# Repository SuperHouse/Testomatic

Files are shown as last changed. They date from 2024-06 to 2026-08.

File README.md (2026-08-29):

Testomatic PCB Test Jig System
==============================

Copyright 2024-2026 SuperHouse Automation Pty Ltd  [www.superhouse.tv]()

Testomatic is an open-source PCB test jig system with several goals:

1. Minimise reinvention when creating a test jig for a new **Device
Under Test (DUT)**.
2. Provide enough built-in I/O to **make the majority of tests easy**, with
expandability to **make harder tests possible**.
3. Allow the chassis to be quickly reused for multiple DUTs, with
each DUT having its own **Test Module**.
4. Integration with an **external test management / logging platform** for centralised storage of test results from one or more testers.

Testomatic is based around a Raspberry Pi, with a special PCB to provide additional I/O and protect the Pi from faults that may occur on the DUT. It uses removable Test Modules that provide the mechanical and electrical connection to each specific DUT. Currently we're using a simple Python testrunner script which has support for definition of multiple target boards, and can be controlled via the touchscreen using a control panel created using Node-RED Dashboard v2.

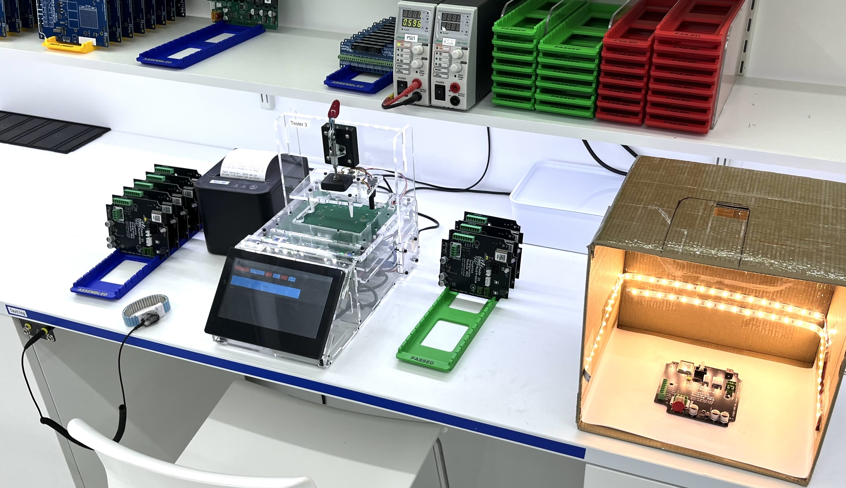
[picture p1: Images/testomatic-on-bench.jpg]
Prototype test jig


This is definitely a work in progress and the design is rapidly
developing. Most development and discussion of this project has taken
place on [SuperHouseTV livestreams](https://www.youtube.com/superhousetv) on YouTube, and on the [SuperHouse
Discord](https://www.superhouse.tv/discord/).

For an overview of how the project came to be and the design goals, see this 
presentation from Everything Open 2026:

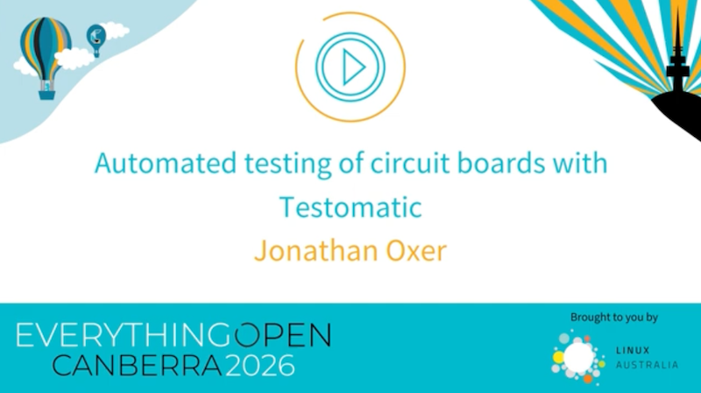
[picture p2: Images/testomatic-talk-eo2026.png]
YouTube (https://www.youtube.com/watch?v=EJt35TPn2Sw)


The new v2 system is still in development and uses a vertically-mounted PCB with a card edge connector for bridging between the Raspberry Pi and the Test Module:

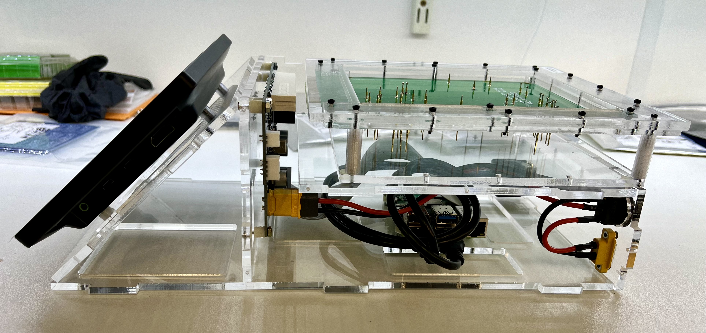
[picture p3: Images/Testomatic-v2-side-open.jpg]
Testomatic v2.0


The v2.3 **Testomatic PCB**:

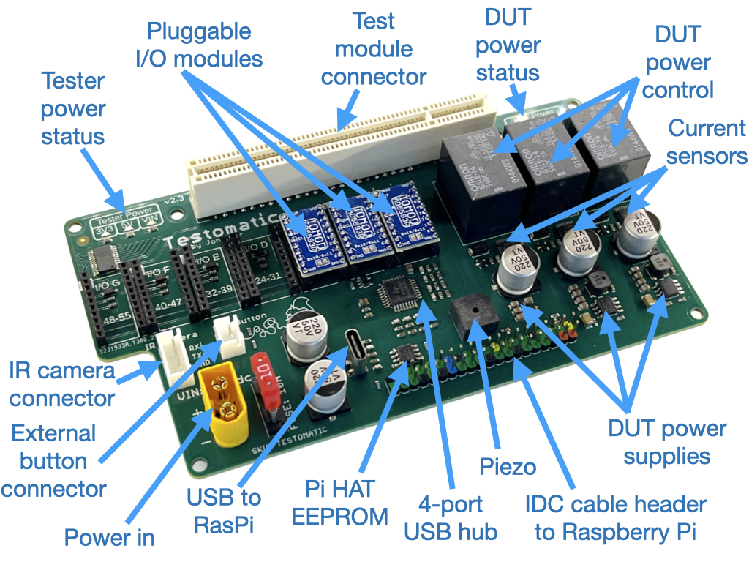
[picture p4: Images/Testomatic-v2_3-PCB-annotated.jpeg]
Testomatic PCB annotated


The **Testomatic PCB** fits into a laser-cut chassis with various other
parts:

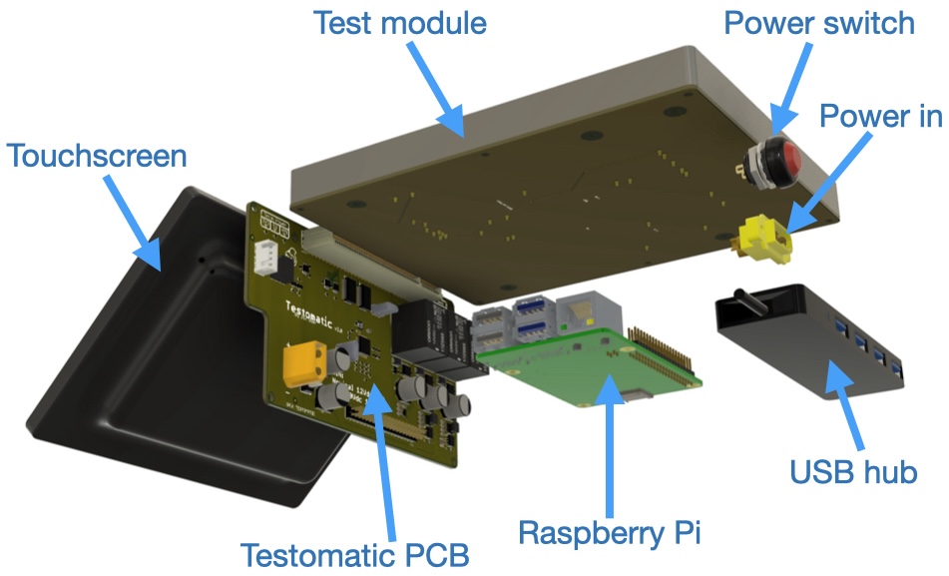
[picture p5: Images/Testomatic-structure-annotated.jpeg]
Testomatic structure


**Test Modules** are built around a **Test Pin Carrier Board (TPCB)** which
uses a card edge connector commonly used for PCI to pass signals
between the Testomatic system and the test pins:

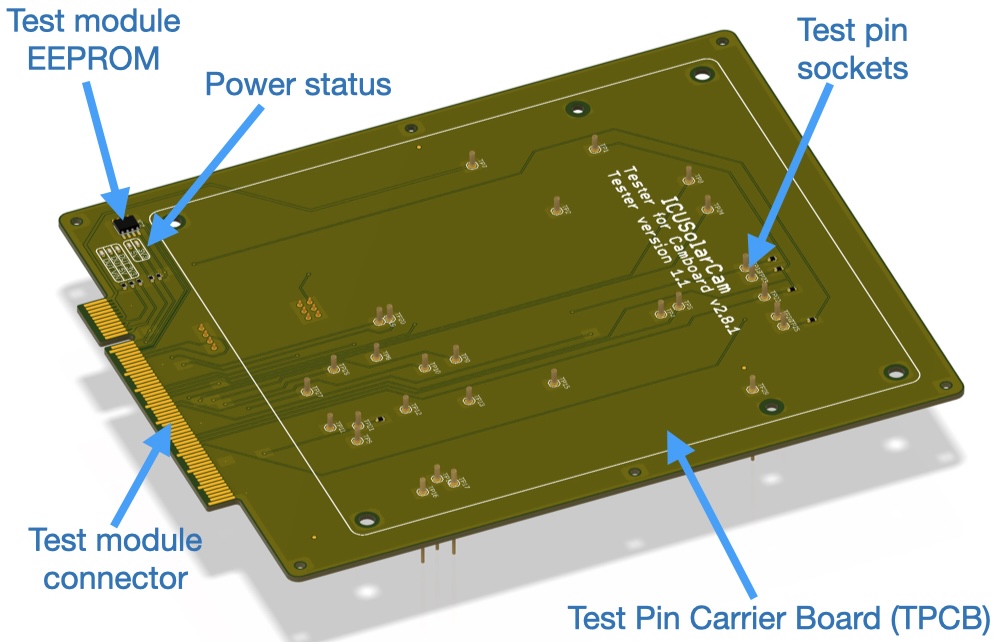
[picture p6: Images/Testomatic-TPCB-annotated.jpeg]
Test Pin Carrier Board


A reference design for the TPCB has been created as a starting point for making DUT-specific versions.

## Features
* 56 GPIOs grouped as 7 blocks, each with 8 pins.
* Each GPIO block can be configured for 3.3V or 5V I/O.
* Each GPIO pin can be digital input, digital output, 12-bit ADC, or 12-bit DAC.
* 4-port USB hub with all 4 ports passed up to the test module.
* SPI and I2C passed up to test module.
* Pi HAT EEPROM on Testomatic PCB for compliance with HAT automatic configuration.
* I2C EEPROM can be placed on Test Module to allow Testomatic to automatically identify which module is loaded.
* 5V power supply dedicated to Raspberry Pi independently of the DUT.
* 5V power supply with current sensing dedicated to DUT.
* 3V3 power supply with current sensing dedicated to DUT.
* VIN is passed to DUT with current sensing.
* Independent relay control of all 3 power rails to DUT.
* 1024 x 600 capacitive touchscreen.
* USB hub mounted in chassis for external connection of receipt printer, barcode scanner, keyboard, etc.
* Support for a 32-24 pixel thermal camera that can be mounted externally for capturing thermal images of the DUT.
* Support for an external button, such as a foot switch for control of test start.

## I/O Modules

Each block of 8 I/O pins is exposed on an I/O Module header, in 2mm pitch DIP format. This allows the use of different I/O modules to suit your needs. A generic I/O Module has been designed based on the AD5593R I2C I/O expander chip. Any pin on this module can be configured to be a digital input or output, analog input, or analog output.

Details of the module are available at [github.com/SuperHouse/IOMOD](https://github.com/SuperHouse/IOMOD)

The plan is to create other modules with different capabilities if required.

## Expansion
Simple tests can be done with the included I/O pins, but many DUTs will require more specific connections. Because the Test Module has SPI, I2C, and USB available, you can build your own custom circuitry directly into the Test Pin Carrier Board. This could include:

* USB-to-Serial converters
* CAN bus interfaces
* RS485 interfaces
* Dummy loads (either onboard or external)
* Light sensors
* Signal generators
* Programmable power supplies

To simplify this process for common tests, we have begun creating small modules that can be added quickly to the design of your Test Pin Carrier Board to save you doing this yourself. These modules include:

 * [USB-to-Serial / ESPFlasher](https://github.com/SuperHouse/ESPFMOD) (complete)
 * [CAN bus](https://github.com/SuperHouse/CANMOD) (complete)
 * [UPDI Programmer / Serial Module](https://github.com/SuperHouse/UPDIMOD)] (complete)

## LED Testing

Instead of relying on visual confirmation by an operator, Testomatic can use light sensors to 
validate correct operation of LEDs. These sensors can detect not only the level of illumination, 
but also the intensity at different wavelengths to verify that the correct colour of LED has 
been placed.

The "ColourSensor" directory contains Fusion design files and STLs for 30mm-long shrouds for 
mounting a VEML3328SL colour sensor, which in turn can be connected via I2C to the Testomatic. 

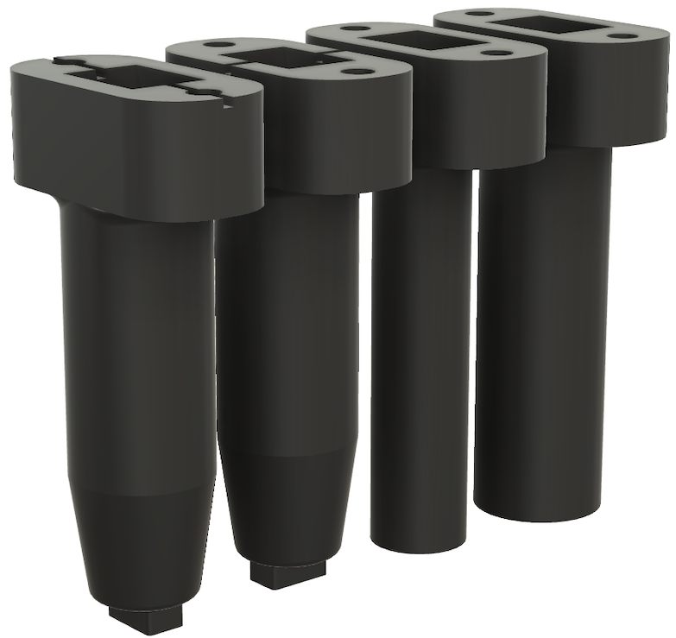
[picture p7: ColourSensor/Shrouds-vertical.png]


Designs are provided to suit 0603 LEDs in both straight and lateral orientations, and 3mm and 
5mm PTH LEDs.

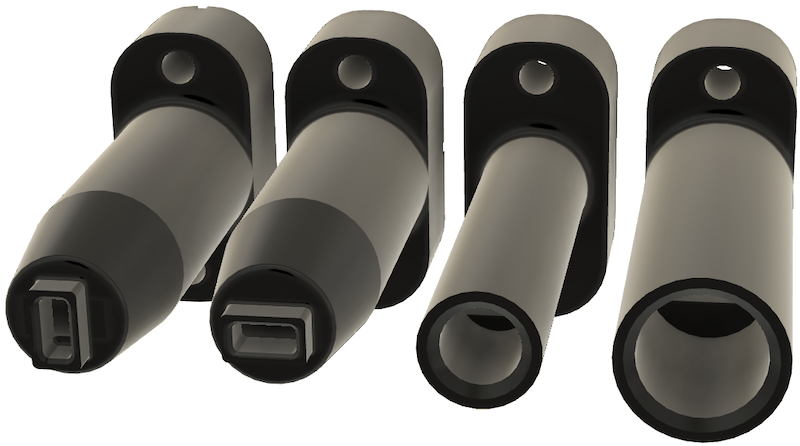
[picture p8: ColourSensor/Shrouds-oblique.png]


The VEML3328SL can be carefully hand-soldered to the ends of thin wires connected to a JST-SH 
1mm connector for compatibility with Qwiic and Stemma, including breakout boards and multiplexers.

The VEML3328SL has a fixed I2C address of 0x10 so a common approach is to use a TCA9548A or 
PCA9546A I2C multiplexer to allow multiple colour sensors to be used.

## Testomatic Circuit Board Register

A closely related project is the Testomatic Circuit Board Register, which is software that 
provides a central location for storing production and testing data related to printed 
circuit board assembly (PCBA) services.

You can use Testomatic without the Register, and you can use the Register without Testomatic, 
but they are being developed in parallel with the intention that they complement each other 
and integrate smoothly.

Lean more about the Register at [github.com/SuperHouse/register](https://github.com/SuperHouse/register).

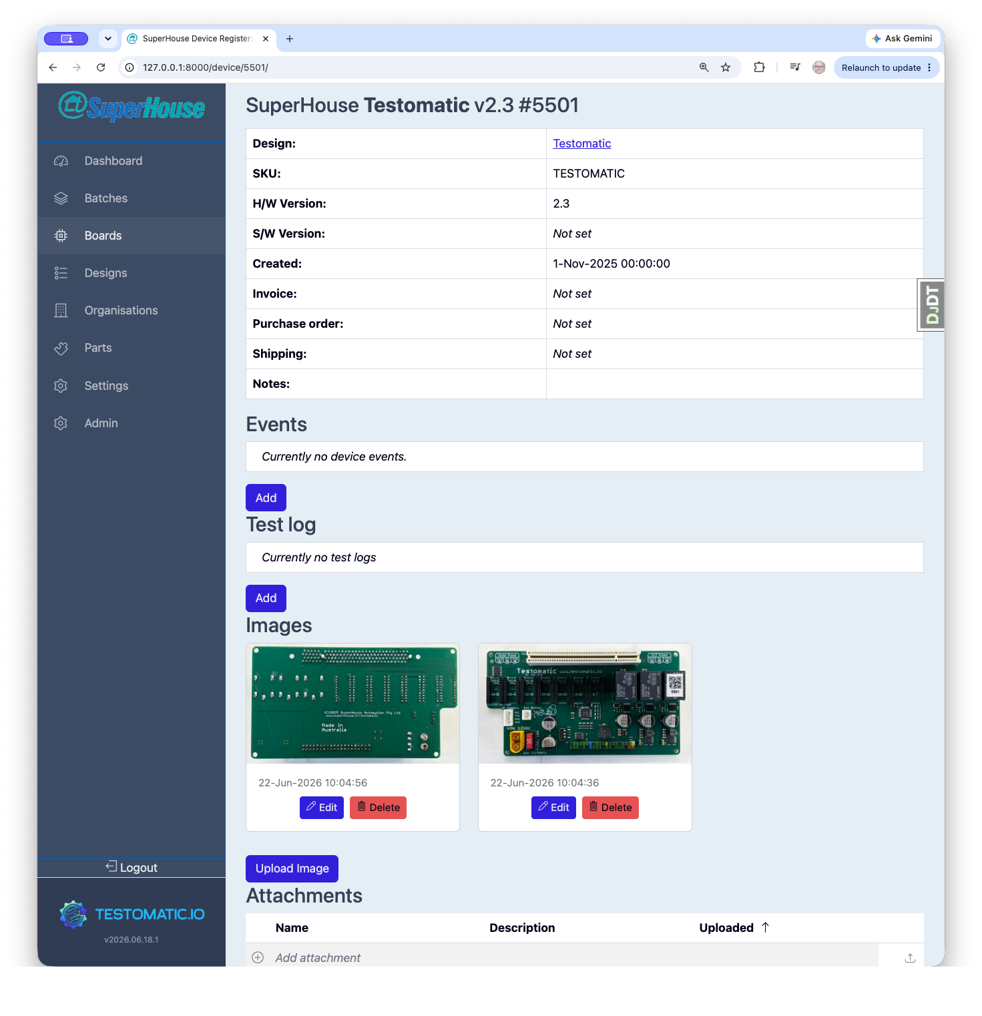
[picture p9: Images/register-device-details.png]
Testomatic v2.0 (https://github.com/SuperHouse/register)


## Installation
Schematic and PCB were created in Fusion360 and exported as EAGLE format,
which can be imported back into Fusion360 or various other packages including KiCAD.

## Terminology
Chassis: A general purpose test jig that can execute tests.

Design: The abstract design of a type of printed circuit board, including the product name, SKU, schematic, PCB layout, bill of materials, and other production data.

Device: An assembled circuit board that is a concrete instantiation of a Design with an identifier such as a serial number that allows it to be unambiguously differentiated from other Devices of the same Design.

Device Under Test / DUT: When a Device is fitted into a Test Module in a Chassis so that it can be tested, it can be referred to as the Device Under Test.

Test Module: Hardware shim that fits into a Chassis and provides connections to a specific DUT.

Test Item: An abstract definition of an action that can be performed while testing a DUT, such as measurign a power rail, or sending a signal to it.

Test Step: An instantiation of a Test Item with specific configuration details such as which power rail to measure, or which I/O pin to use for sending a signal. Test Steps are executed automatically during the process of testing a DUT.

Manual Check: One step that is executed manually during the process of testing a DUT.

Test Suite: A collection of Test Items and Manual Checks that constitutes the steps required to test a DUT.

Test Run: One execution of a Test Suite against a Device Under Test.

Test Output: The data collected during a Test Run, with values and outcomes that are specific to that Device.

Test Result: Pass/Fail/Abort/Error. Pass: all Test Steps executed within required parameters. Fail: Test Suite was completed, but one or more Test Steps were outside required parameters. Abort: Test Suite was not completed because a Test Step caused the process to abort. Error: Test Suite was not completed because an environmental problem prevented execution.

Register: Software system that stores definitions of Designs, Test Items, and Test Suites, along with production data and Test Results related to Devices.

Test Suite Definition: A JSON file that contains the Test Steps and Manual Checks of a Test Suite.

Test Suite Package: A Test Suite Definition together with the additional artifacts it references and requires for execution, such as firmware binaries, whether delivered as a single archive or assembled from multiple sources such as separate API fetches.

Test Runner: Software that runs on the Chassis to load a Test Suite, execute its Test Steps against a Device, and report the resulting Test Results.

## Credits
Designed by Jonathan Oxer <jon@oxer.com.au> with the assistance of many members of the SuperHouse Discord.

## Distribution
The specific terms of distribution of this project are governed by the
license referenced below.

## License
Licensed under the TAPR Open Hardware License (www.tapr.org/OHL).
The "license" folder within this repository also contains a copy of
this license in plain text format.

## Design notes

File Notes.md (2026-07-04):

# Notes

## Sources Of Inspiration

### Thea's tester

 * [https://twitter.com/theavalkyrie/status/1552714810038657025]()
 * [https://github.com/wntrblm/Hubble]()

### OpenHTF

 * [https://www.openhtf.com/]()

### Gundam

Steven's tester for Opulo. This has been mentioned on various livestreams 
etc and the intention seems to be for it to be released as open source, but 
so far I can't find it anywhere. It's referenced in Opulo docs such as here: 

 * [https://ohai.opulo.io/feeder8/oqc/]()

### qabench htf

Looks like a purely commercial offering and I can't find source anywhere. 
Seems to support a large collection of hardware devices.

 * [https://docs.hilster.io/htf/latest/#]()

### Awesome Hardware Test

A massive list of projects. No point reproducing it here!

 * [https://github.com/sschaetz/awesome-hardware-test]()

## To Validate

 * [OK] TUSB2046 USB hub
 * [OK] DUT power control: VIN, 5V, 3V3
 * [OK] INA260 current sensors (Using library)
 * [OK] Piezo beeper
 * [OK] TCA9548 I2C multiplexer
 * [OK] AD5593R I/O expander
 * CAT24C32 EEPROM (Test Module, on I2C bus 1)
 * CAT24C32 EEPROM (HAT, on I2C bus 0)

## Light Box

Logitech Brio MX 4K webcam

sudo apt install fswebcam

To check available resolutions:

v4l2-ctl --list-formats-ext

Must be plugged into USB3 port and detected as a USB3 device to provide 4K res.

fswebcam -r 3840x2160 -p MJPEG --skip 10 test9.jpg

It's only being detected as USB2.0:

lsusb -t

shows 480M (USB2.0) instead of 5000M (USB3.0) even plugged in directly.

According to Gemini, Pi 3B+ only has a shared internal USB2.0 bus, even 
though it exposes USB3 ports externally! This sucks

Got it working an a Pi 5B with a Comsol USB-A to C cable CMAM12BK

Options like this work, although gain doesn't seem to do anything:

fswebcam -r 3840x2160 -p MJPEG --set brightness=100% --set contrast=60% --set sharpness=80% --set gain=255 --skip 20 test17.jpg

### Stacking images

Script to take a series of pics:

#!/bin/bash

### Create a directory for the images if it doesn't exist
mkdir -p webcam_images
cd webcam_images

### Capture 10 images with a 1-second delay between captures
for i in {1..5}; do
    echo "Capturing image $i..."
    # -r specifies resolution, --no-banner removes the timestamp
    # -S 10 skips the first 10 frames to allow calibration
    fswebcam -r 3840x2160 -p MJPEG --no-banner --set brightness=80% --set contrast=60% --set sharpness=60% --skip 20 image_$i.jpeg
    sleep 1
done

echo "Capture complete."

Install ImageMagick:

sudo apt install imagemagick

Process pics:

magick convert *.jpeg -evaluate-sequence median stacked_image.jpeg

## Printer control

Alternative to using external process and passing it a text file:

https://github.com/python-escpos/python-escpos

## Colour sensing

https://github.com/DevelopiumTech/VEML3328

https://www.digikey.com.au/en/products/detail/vishay-semiconductor-opto-division/VEML3328SL/10673128

https://www.finntestelectronics.com/product/mega-module/

## Writing tests

Use Given - When - Then format? Or AAA?

Use raw Python, or some kind of config? Config is hard! For eg:

## How to format error message with results?

Simple string, then output of all "then" lines?

object:
  title: 5V power rail
  abort_on_fail: true
  fail_message: 5V power rail out of spec
  given:
    - 5v: true
    - boolean: true
  when:
    - 5v: true
    - delay: 100ms
  then:
    - analogread a5: 4.7 - 5.1
    
object:
  title: 3V3 power rail
  abort_on_fail: true
  fail_message: 3V3 power rail out of spec
  given:
    - 5v: true
    - boolean: true
  when:
    - 5v: true
    - delay: 100ms
  then:
    - analogread a6: 2.9 - 3.4

## TCA9548 I2C multiplexer

Needs Blinka installed:

https://learn.adafruit.com/circuitpython-on-raspberrypi-linux/installing-circuitpython-on-raspberry-pi

    sudo apt-get update
    sudo apt-get -y upgrade
    sudo apt-get install -y python3-pip

    pip install rpi-lgpio

https://learn.adafruit.com/adafruit-tca9548a-1-to-8-i2c-multiplexer-breakout/circuitpython-python

    sudo pip3 install adafruit-circuitpython-tca9548a

## AD5593R I/O expander

https://github.com/101Robotics/AD5593-MicroPython

https://learn.adafruit.com/adafruit-ad5693r-16-bit-dac-breakout-board/circuitpython-and-python

    python -m venv venv
    source venv/bin/activate
    pip install adafruit-circuitpython-ad569x
    pip install lgpio

## Pi power control

To allow Node-RED to shut down the Pi:

https://flows.nodered.org/node/node-red-contrib-rpi-shutdown

## INA260 current sensors

https://pypi.org/project/ina260/

    pip install ina260
    
    from ina260.controller import Controller
    c = Controller(address=0x40)
    print(c.voltage())
    print(c.current())
    print(c.power()))

## MCP23017 I/O expanders

Use Adafruit Blinka for CP style access to MCP23017 from within Python:

https://learn.adafruit.com/using-mcp23008-mcp23017-with-circuitpython/python-circuitpython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

Created a test script called mcp-test.py

Pullup example:

    pin1.direction = digitalio.Direction.INPUT
    pin1.pull = digitalio.Pull.UP

## DUT Power Control
    pinctrl 17 op dh   // Turn on VIN
    pinctrl 27 op dh   // Turn on 5V
    pinctrl 22 op dh   // Turn on 3.3V

## Piezo control
    pinctrl 23 op dh   // Turn on piezo
    pinctrl 23 op dl   // Turn off piezo

## Data import

Export spreadsheet from gdocs as XLSX, and scp it to the portal VM.

    cd /var/www/register-test/pyproj
    . env/bin/activate
    ./manage.py import-xlsx ~/Device-Serial-Numbers-.xlsx

## Label printer

Brother label printer on Linux: [https://github.com/HenrikBengtsson/brother-ptouch-label-printer-on-linux]()

For CAN:
MCP251863 controller/ transceiver
(See CANPico board)

[https://github.com/kentindell/canhack/tree/master/CANPico]()

[https://core-electronics.com.au/adafruit-picowbell-can-bus-for-pico-mcp2515-can-controller.html]()

[https://github.com/LukePrior/Raspberry-Pi-Thermal-Printer]()

Firmata for Raspberry Pi Pico:

 * Use ConfigurableFirmata with zero changes
 * Board profile is "Arduino Mbed OS RP2040 Boards" -> "Raspberry Pi Pico"
 * Upload methd: UF2

Impressive 3D printed test jig run by a Raspberry Pi:

[https://www.youtube.com/watch?v=iTLnJ0uIZIg]()

Firmata equivalent for RPi Pic:

[https://github.com/MrYsLab/telemetrix-rpi-pico]()

Equivalent to Firmata:

[https://abyz.me.uk/picod/py_picod.html]()

Config files using configparser:

[https://stackoverflow.com/questions/19078170/python-how-would-you-save-a-simple-settings-config-file]()

[https://www.geeksforgeeks.org/how-to-create-gui-applications-under-linux-desktop-using-pygobject/]()

Thermal camera for Raspberry Pi:

[https://www.flir.com.au/developer/lepton-integration/lepton-integration-raspberry-pi/]()

Capturing from Raspberry Pi cam:

    raspistill -st -t 200 -o image.jpg

## Process

Install Raspberry Pi OS 64-bit. Edit the settings:

 * Set hostname to tester(x).local
 * Set username to testomatic
 * Set password to something secret
 * Set WiFi credentials
 * Set WiFi country
 * Set locale
 * Enable SSH

Put SD card in Pi and boot it.

SSH to the pi:

    ssh testomatic@tester.local

Update system and install Vim:

    sudo apt update
    sudo apt dist-upgrade
    sudo apt install vim

Install node-red

Go to http://tester3.local:1880/

Install the palette item "node-red-contrib-ip"
Install the palette item "@flowfuse/node-red-dashboard"

    sudo apt install pipx
    pipx install esptool

Kiosk tutorial: https://www.raspberrypi.com/tutorials/how-to-use-a-raspberry-pi-in-kiosk-mode/

    sudo apt install wtype
    sudo apt install chromium-browser

    sudo vim .config/wayfire.ini

Add this new section:

[autostart]
chromium = chromium-browser http://localhost:1880/dashboard/page1 --kiosk --noerrdialogs --disable-infobars --no-first-run --ozone-platform=wayland --enable-features=OverlayScrollbar --start-maximized

    sudo apt install chromium-browser

Add to /etc/xdg/lxsession/LXDE-pi/autostart:

@xset s off
@xset -dpms
@xset s noblank
@chromium-browser --noerrdialogs --disable-infobars --kiosk https://localhost:1880/dashboard/page1

### Enable Screen

edit /boot/firmware/config.txt and find this line:

    dtoverlay = vc4-kms-v3d

Replace it with:

    dtoverlay = vc4-fkms-v3d

    sudo vim /boot/firmware/config.txt
    
Add these lines to the end:

    hdmi_force_hotplug=1
    max_usb_current=1
    hdmi_group=2
    hdmi_mode=1
    hdmi_mode=87
    hdmi_cvt 1024 600 60 6 0 0 0
    hdmi_drive=1

Elecrow 7" touchscreen setup: [https://www.elecrow.com/rc070p-7-inch-1024x600-raspberry-pi-monitor-touchscreen-capacitive-ips-display-with-built-in-speaker-stand.html](https://www.elecrow.com/rc070p-7-inch-1024x600-raspberry-pi-monitor-touchscreen-capacitive-ips-display-with-built-in-speaker-stand.html)

### Receipt Printer Driver

copy printer-driver-pos_3.13.11_all.deb to machine

    sudo dpkg -i printer-driver-pos_3.13.11_all.deb

Open printer preferences and enable network administration.

Use a browser to connect to https://tester.local:631

Add local printer.

Select the POS-80.

On the printer type page, select Make -> POS
Select Model -> POS-80 (en)

### Install Software

Copy over test software directory.

    pip3 install pytz
    pip3 install esptool

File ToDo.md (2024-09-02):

Testomatic To Do
================

 * Silkscreen on XT60 footprint.
 * Reverse protection diode on VIN. Mitchell says full bridge rectifier. Which is ridiculous. But also awesome.
 * Increase thermal relief widths on edge connector GND pins and XT60 connector.
 * Length-match USB traces.
 * Add solder wicking area beside USB mechanical holes
 * Add bolt holes to XT60 footprint for panel mount version of connector (maybe)
 * Connector for RGB LED strip to illuminate enclosure.
 * Blatantly steal Austin's Smart Hub design
 * Solder-nuts on PCB to avoid standoffs. Thanks Austin!

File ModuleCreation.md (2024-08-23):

= Creating a Test Module

The Test Module supports the DUT mechanically, and connects it electrically
to the test system.

== Laser-cut frame

1. Open "Module Plate Template" in Fusion360.
2. Open "Modify" -> "Parameters".
3. Set "DUTWidth" to the horizontal width of your DUT.
4. Set "DUTLength" to the front-back length of your DUT.
5. Set "DUTFrontOffset" to the distance from the front of your Test Pin Carrier Board and the front edge of your DUT when mounted on it.
6. Close parameters dialog.
7. Turn on Bodies -> Top Plate AND Bottom Plate.
8. Create mounting holes to suit the design of your Test Pin Carrier Board.
9. Turn on only Bodies -> Top Plate, select top surface, and save as DXF for lasercutting.
10. Turn on only Bodies -> Bottom Plate, select top surface, and save as DXF for lasercutting.
11. Laser-cut both parts using 4.5mm acrylic. The thickness of the bottom plate is critical to set the vertical alignment of the connector.
12. Bolt the Top Plate and the Bottom Plate together using M2 bolts. You can optionally countersink them for a smooth top surface.
13. Bolt your Test Pin Carrier Board to the bottom of the assembly.

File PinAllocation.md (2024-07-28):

Raspberry Pi Pins
=================

IO0: Raspberry Pi HAT EEPROM I2C SDA. EEPROM is on the Testomatic main board.

IO1: Raspberry Pi HAT EEPROM I2C SCL. EEPROM is on the Testomatic main board.

IO2: General purpose I2C SDA. Can be used for peripherals on the breakout.

IO3: General purpose I2C SCL. Can be used for peripherals on the breakout.

IO4: Spare

IO5: Spare

IO6: Spare

IO7: SPI CE1

IO8: SPI CE0

IO9: SPI MISO

IO10: SPI MOSI

IO11: SPI SCK

IO13: Spare

IO14: Infrared camera TX (to the Rx of the camera)

IO15: Infrared camera RX (to the Tx of the camera)

IO16: Spare

IO17: Spare

IO18: Tester reset. Active low, with 10K pullup. Connected to !RESET pins on devices that are part of the tester.

IO19: Spare

IO20: External button. Active low, with 10K pullup. Short to GND to activate. Can be used by tester to begin test, etc.

IO21: Spare

IO22: Spare

IO23: Piezo buzzer. Active high.

IO24: Available on tester breakout. Can be used as an SPI CE, for example.

IO25: Available on tester breakout. Can be used as an SPI CE, for example.

IO26: Spare

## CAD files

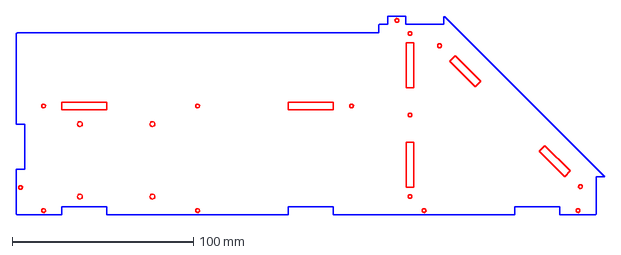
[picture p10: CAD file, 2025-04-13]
Chassis/Side Plate Right.dxf
324.8 x 109.6 mm

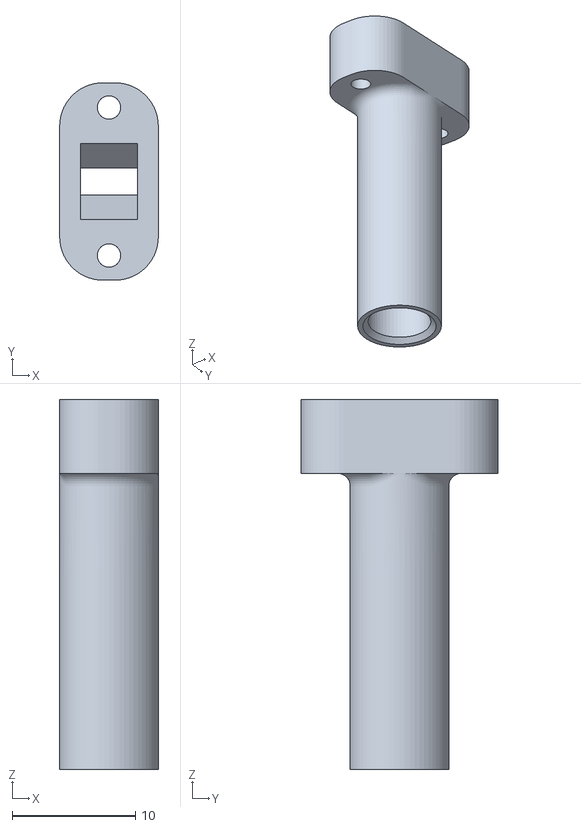
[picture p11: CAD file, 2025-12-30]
ColourSensor/Shroud 5mm.stl
8.00 x 16.0 x 30.0

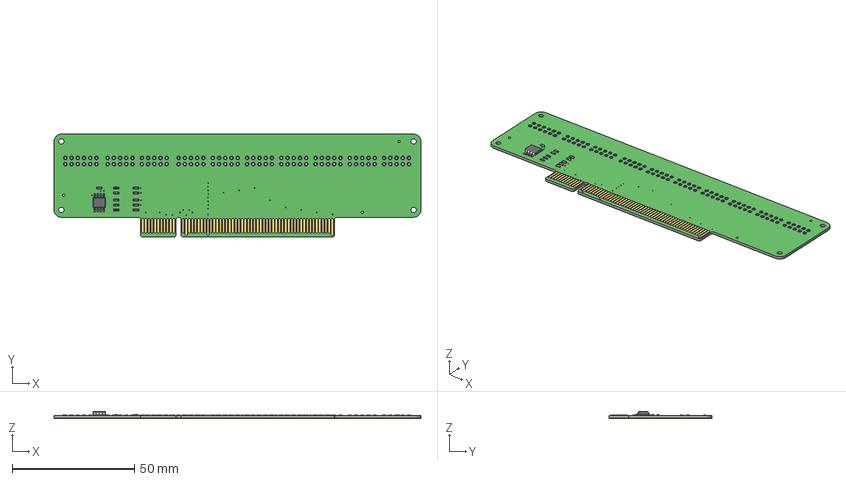
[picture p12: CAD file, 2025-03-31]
TestModules/TMMOD-BREAKOUT-v1_1.3mf
150.0 x 42.0 x 2.80 mm
Board
CopperHoles

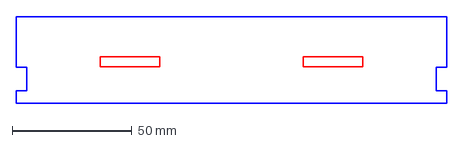
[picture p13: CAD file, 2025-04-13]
Chassis/Cap Plate.dxf
180.2 x 36.2 mm

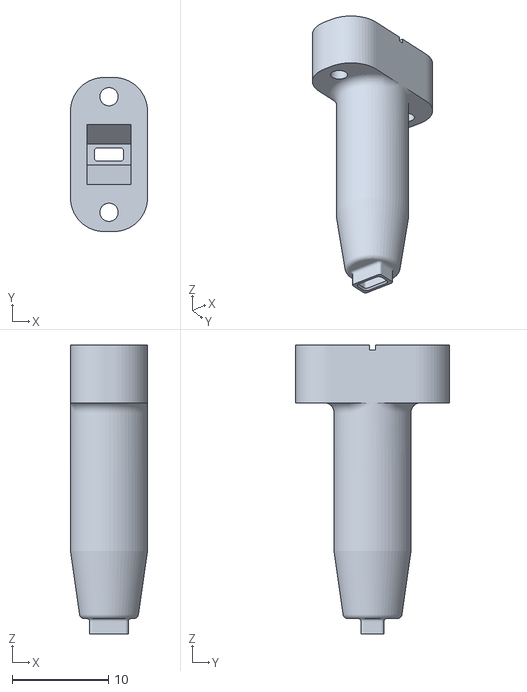
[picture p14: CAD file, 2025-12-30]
ColourSensor/Shroud 0603 lateral.stl
8.00 x 16.0 x 30.0

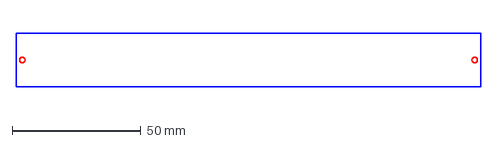
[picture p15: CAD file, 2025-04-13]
Chassis/Chin Plate.dxf
180.2 x 20.7 mm

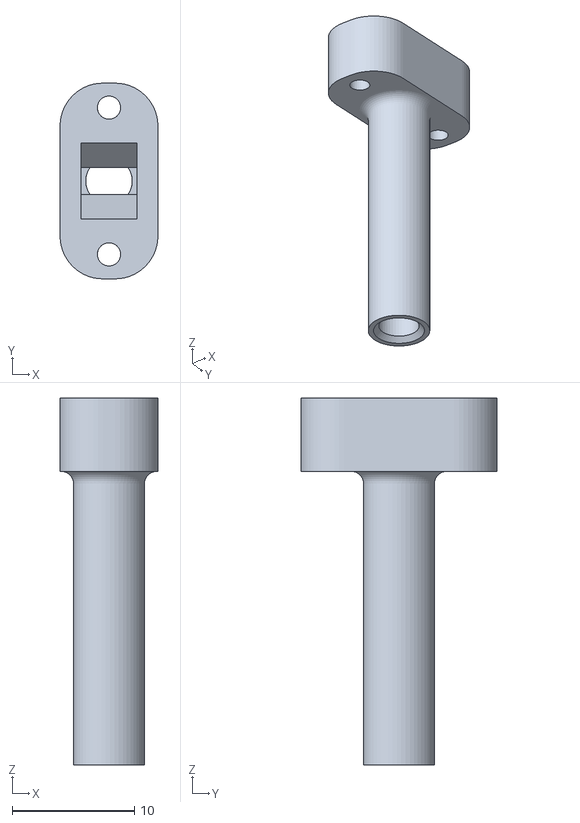
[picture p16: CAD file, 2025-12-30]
ColourSensor/Shroud 3mm.stl
8.00 x 16.0 x 30.0

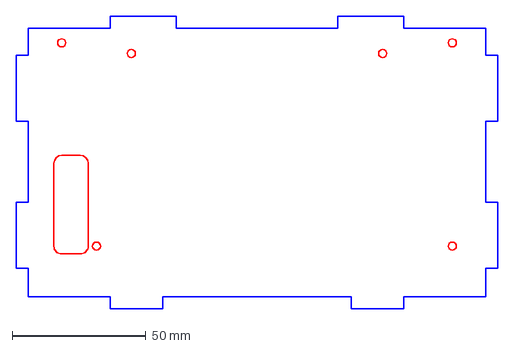
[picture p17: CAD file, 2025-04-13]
Chassis/PCB Plate.dxf
179.8 x 109.3 mm

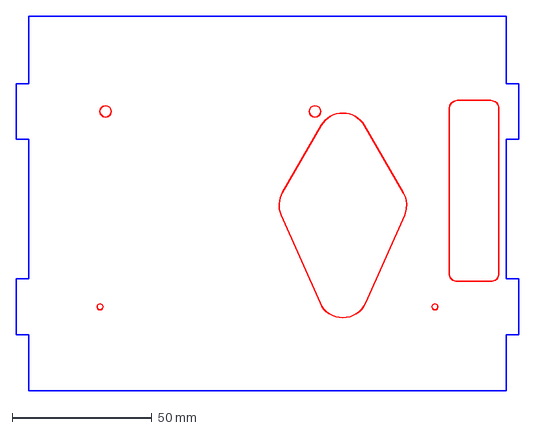
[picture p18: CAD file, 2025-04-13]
Chassis/Display Plate.dxf
180.2 x 134.1 mm

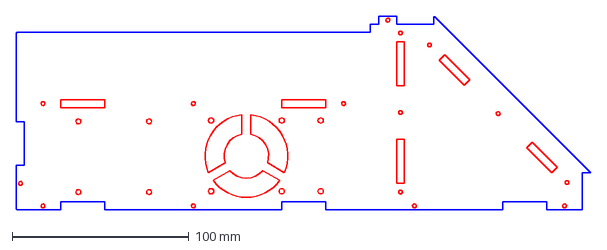
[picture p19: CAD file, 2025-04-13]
Chassis/Side Plate Left.dxf
324.8 x 109.6 mm

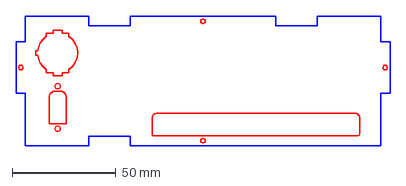
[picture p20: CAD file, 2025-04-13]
Chassis/Back Plate.dxf
180.2 x 62.2 mm

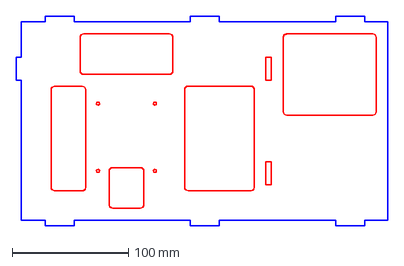
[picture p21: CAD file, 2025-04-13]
Chassis/Base Plate.dxf
320.1 x 180.1 mm

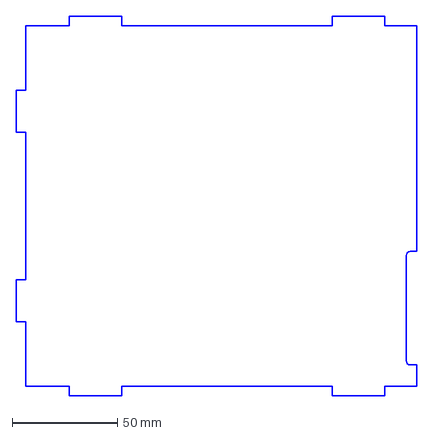
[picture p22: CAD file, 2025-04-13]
Chassis/Deck Plate.dxf
190.1 x 180.1 mm

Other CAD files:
ColourSensor/Shroud 0603 straight.stl
Chassis/Back Plate.f3d
Chassis/Base Plate.f3d
Chassis/Cap Plate.f3d
Chassis/Chin Plate.f3d
Chassis/Deck Plate.f3d
Chassis/Display Plate.f3d
Chassis/PCB Plate.f3d
Chassis/Side Plate Left.f3d
Chassis/Side Plate Right.f3d
ColourSensor/Shroud 0603 lateral.f3d
ColourSensor/Shroud 0603 straight.f3d
ColourSensor/Shroud 3mm.f3d
ColourSensor/Shroud 5mm.f3d
TestModules/Module Plate Template.f3d

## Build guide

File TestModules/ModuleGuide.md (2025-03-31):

Creating a Test Module
======================

The Test Module supports the DUT mechanically, and connects it electrically
to the test system.

You need to create one test module for each type of device that you wish to test. Test modules
can be swapped out as required.

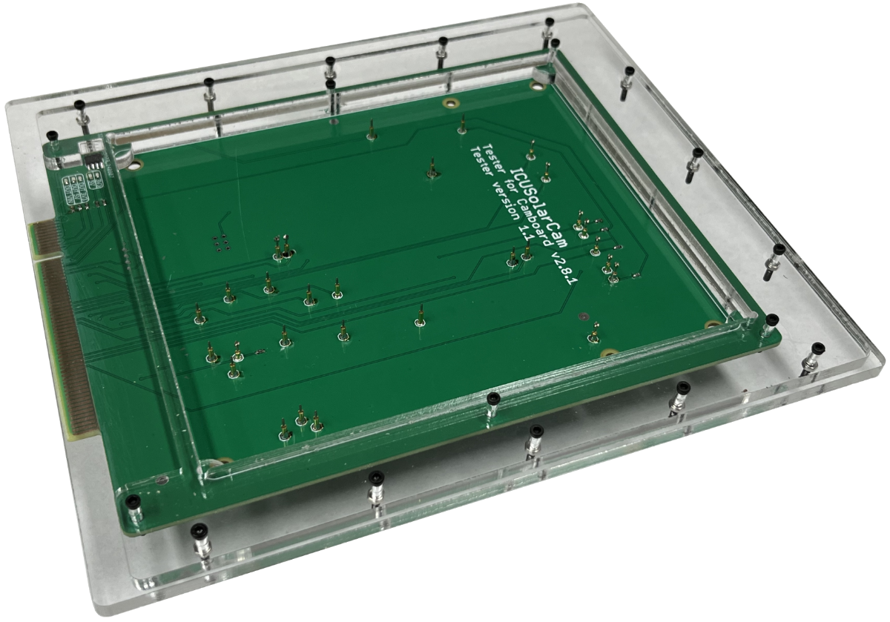
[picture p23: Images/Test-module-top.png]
Test module


## Test Pin Carrier Board (TPCB)

To do: Notes here about designing your TPCB.

## Laser-cut frame

1. Open "Module Plate Template" in Fusion360.
2. Open "Modify" -> "Parameters".

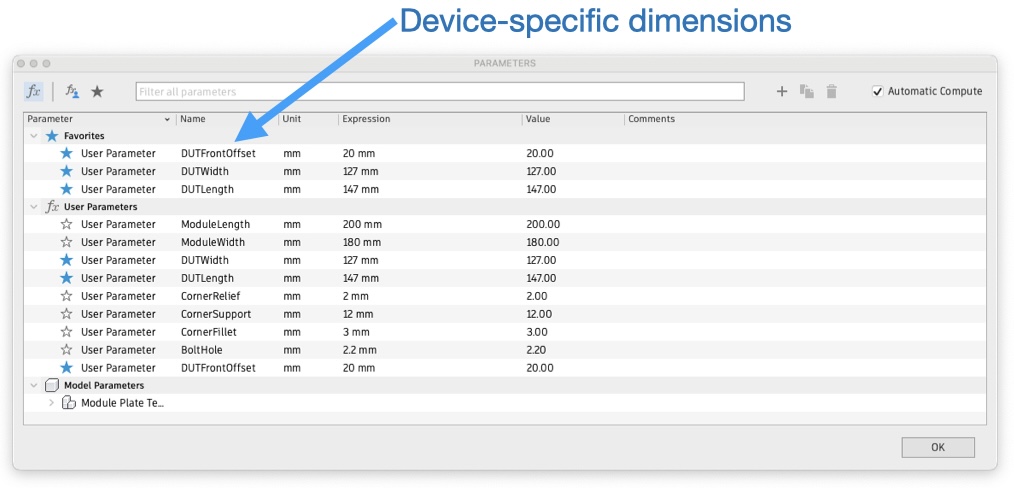
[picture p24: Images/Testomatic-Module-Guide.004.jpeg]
Module parameters


3. Set "DUTWidth" to the horizontal width of your DUT.
4. Set "DUTLength" to the front-back length of your DUT.
5. Set "DUTFrontOffset" to the distance from the front of your Test Pin Carrier Board and the front edge of your DUT when mounted on it.
6. Close parameters dialog.
7. Turn on Bodies -> Top Plate AND Bottom Plate.
8. Create mounting holes to suit the design of your Test Pin Carrier Board.
9. Turn on only Bodies -> Top Plate, select top surface, and save as DXF for lasercutting.
10. Turn on only Bodies -> Bottom Plate, select top surface, and save as DXF for lasercutting.

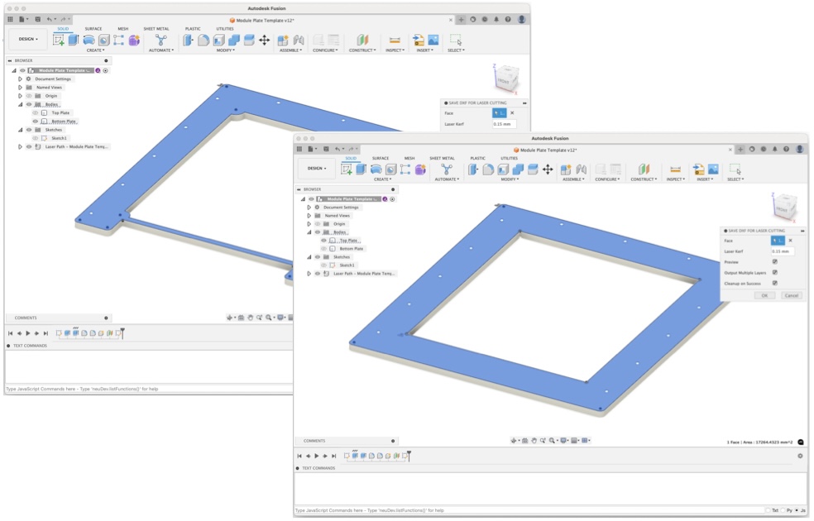
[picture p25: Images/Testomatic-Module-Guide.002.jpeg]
Export for lasercutting


11. Laser-cut both parts using 4.5mm acrylic. The thickness of the bottom plate is critical to set the vertical alignment of the connector.
12. Bolt the Top Plate and the Bottom Plate together using M2 bolts. You can optionally countersink them for a smooth top surface.
13. Bolt your Test Pin Carrier Board to the bottom of the assembly.

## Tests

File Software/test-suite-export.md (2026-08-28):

# Test Suite Export Format

A Test Suite is the ordered list of Test Steps and Manual Checks for a
[Design](../user-guide/designs.md). You can download a Test Suite as a single JSON file. This
page describes that JSON format. Use it to build external tools, such as a Testomatic tester,
that read or write Test Suites.

## Downloading a Test Suite

Only staff users can download a Test Suite. To download one, open the Design detail page and go
to the **Test Suite** tab. Click **Download**.

The download contains the version shown on the tab. This is the draft version if one exists. If
not, it is the current saved version.

The filename follows this pattern:

```
{sku}-hw{hw_version}-test-suite-v{version}.json
```

For example, `abc123-hw1-0-test-suite-v3.json`.

## Envelope structure

The file is a single JSON object with four top-level keys:

```json
{
  "export_schema_version": 1,
  "design": { "...": "..." },
  "test_suite": { "...": "..." },
  "test_steps": [ "..." ],
  "manual_checks": [ "..." ]
}
```

`export_schema_version` identifies the shape of the envelope: its top-level keys and their
nesting. The Register increases this number only when that shape changes, for example when a
top-level key changes name. It differs from `config_schema_version`, described below, which
tracks the shape of one step's own configuration fields.

### `design`

This object identifies the Design that the Test Suite belongs to:

| Field | Type | Description |
|---|---|---|
| `id` | integer | The Design's database ID |
| `sku` | string | The Design's SKU |
| `name` | string | The Design's name |
| `hw_version` | string | The Design's hardware version |

### `test_suite`

This object describes this version of the Test Suite:

| Field | Type | Description |
|---|---|---|
| `version` | integer | Version number, starting at 1 |
| `status` | string | `"DRAFT"` or `"SAVED"` |
| `notes` | string or `null` | Free-text notes the user enters when saving this version |
| `created_dt` | string | ISO 8601 timestamp showing when the Register created this version |

### `test_steps`

This is an array of Test Step objects, listed in execution order. Every step has the same outer
shape, regardless of type:

| Field | Type | Description |
|---|---|---|
| `order` | integer | Position within the suite (ascending) |
| `step_type` | string | One of the step type codes listed below |
| `name` | string | The step's display name |
| `hard_fail` | boolean | If `true`, a failure of this step stops the rest of the suite |
| `config_schema_version` | integer or `null` | The schema version of `config` below (`null` if the step predates schema versioning) |
| `config` | object | Type-specific configuration fields. See [Test Step types](#test-step-types) below |

`config_schema_version` copies the `schema_version` key already inside `config`. The Register
places it at this outer level so a consumer does not need to open the nested object to find it.
This number increases only when a step type's own config fields change shape. It is independent
of `export_schema_version` above.

### `manual_checks`

This is an array of Manual Check objects, listed in order. It is a plain checklist shown
alongside the Test Steps. Each item has no type or config fields of its own:

| Field | Type | Description |
|---|---|---|
| `order` | integer | Position within the list (ascending) |
| `text` | string | The checklist item's text |

## Test Step types

Each step's `config` object holds only the fields for its `step_type`. The Register omits an
**optional** field from `config` when it has no value. A consumer should apply its own default
instead of expecting a null or empty value for that key.

### `DELAY`

Waits a fixed number of milliseconds.

| Field | Type | Required | Description |
|---|---|---|---|
| `delay_ms` | integer | Yes | Delay in milliseconds |

### `UPLOAD_FIRMWARE`

Uploads a firmware image to the device under test.

| Field | Type | Required | Description |
|---|---|---|---|
| `upload_tool` | string | Yes | One of `avrdude`, `esptool.py`, `openocd`, `stm32cubeprogrammer` |
| `port` | string | Yes | Serial port / device identifier |
| `firmware_file` | string | Yes | Firmware binary filename |

### `BEEP`

Sounds a beep, or a sequence of beeps.

| Field | Type | Required | Description |
|---|---|---|---|
| `duration_ms` | integer | Yes | Duration of each beep, in milliseconds |
| `count` | integer | No | Number of beeps. A consumer should use `1` as the default when this field is absent |

### `READ_RAIL_VOLTAGE`

Reads a power rail's voltage. Checks that the reading falls within the given range.

| Field | Type | Required | Description |
|---|---|---|---|
| `rail` | string | Yes | One of `3.3V`, `5V`, `12V` |
| `min_v` | number | Yes | Minimum acceptable voltage |
| `max_v` | number | Yes | Maximum acceptable voltage |

### `READ_RAIL_CURRENT`

Reads a power rail's current draw. Checks that the reading falls within the given range.

| Field | Type | Required | Description |
|---|---|---|---|
| `rail` | string | Yes | One of `3.3V`, `5V`, `12V` |
| `min_ma` | number | Yes | Minimum acceptable current, in mA |
| `max_ma` | number | Yes | Maximum acceptable current, in mA |

### `CONTROL_POWER_RAIL`

Turns a power rail on or off.

| Field | Type | Required | Description |
|---|---|---|---|
| `rail` | string | Yes | One of `3.3V`, `5V`, `12V` |
| `action` | string | Yes | `ON` or `OFF` |

### `PYTHON`

Runs a block of Python code as the test step. The Register does not execute this code. It is
configuration data for a Testomatic tester, or another consumer, to run.

| Field | Type | Required | Description |
|---|---|---|---|
| `python_code` | string | Yes | Python source code |

### `IOMOD_ANALOG_READ`

Reads an analog value from an IOMOD pin. Optionally checks that the value falls within a range.

| Field | Type | Required | Description |
|---|---|---|---|
| `iomod` | string | Yes | IOMOD identifier, `A`–`G` |
| `pin` | string | Yes | Pin number, `0`–`7` |
| `expect_min` | integer | No | Minimum acceptable reading |
| `expect_max` | integer | No | Maximum acceptable reading |

### `IOMOD_DIGITAL_READ`

Reads a digital value from an IOMOD pin. Checks the value against an expected value.

| Field | Type | Required | Description |
|---|---|---|---|
| `iomod` | string | Yes | IOMOD identifier, `A`–`G` |
| `pin` | string | Yes | Pin number, `0`–`7` |
| `expect` | string | Yes | Expected value, `"0"` or `"1"` |

### `IOMOD_DIGITAL_WRITE`

Writes a digital value to an IOMOD pin.

| Field | Type | Required | Description |
|---|---|---|---|
| `iomod` | string | Yes | IOMOD identifier, `A`–`G` |
| `pin` | string | Yes | Pin number, `0`–`7` |
| `digital_write` | string | Yes | Value to write, `"0"` or `"1"` |

### `IOMOD_ANALOG_WRITE`

Writes an analog value to an IOMOD pin.

| Field | Type | Required | Description |
|---|---|---|---|
| `iomod` | string | Yes | IOMOD identifier, `A`–`G` |
| `pin` | string | Yes | Pin number, `0`–`7` |
| `analog_write` | integer | Yes | Value to write |

### `LED_SPECTRAL_READING`

Reads color and light values from an I2C spectral sensor. The sensor may connect through a MUX.
The step can optionally check that each channel falls within a range.

| Field | Type | Required | Description |
|---|---|---|---|
| `i2c_addr` | string | Yes | Sensor's I2C address, as hex text, for example `"0x29"` |
| `mux_chan` | string | Yes | MUX channel, `0`–`7` |
| `mux_addr` | string | No | MUX's I2C address, as hex text, for example `"0x71"`. Omitted if the board has no MUX in the path |
| `r_min` / `r_max` | integer | No | Red channel acceptable range |
| `g_min` / `g_max` | integer | No | Green channel acceptable range |
| `b_min` / `b_max` | integer | No | Blue channel acceptable range |
| `lux_min` / `lux_max` | integer | No | Lux (brightness) acceptable range |
| `ir_min` / `ir_max` | integer | No | Infrared channel acceptable range |

### `OPERATOR_INTERVENTION`

Displays an instruction to a human operator and waits for the operator to act. Unlike other step
types, it does not take an automated reading.

| Field | Type | Required | Description |
|---|---|---|---|
| `message` | string | Yes | Instruction text shown to the operator |

## Example

```json
{
  "export_schema_version": 1,
  "design": {
    "id": 42,
    "sku": "ABC123",
    "name": "Example Board",
    "hw_version": "1.0"
  },
  "test_suite": {
    "version": 3,
    "status": "SAVED",
    "notes": "Added LED spectral check",
    "created_dt": "2026-08-20T09:15:00+10:00"
  },
  "test_steps": [
    {
      "order": 1,
      "step_type": "DELAY",
      "name": "Settle",
      "hard_fail": false,
      "config_schema_version": 1,
      "config": { "schema_version": 1, "delay_ms": 250 }
    },
    {
      "order": 2,
      "step_type": "READ_RAIL_VOLTAGE",
      "name": "Check 5V rail",
      "hard_fail": true,
      "config_schema_version": 1,
      "config": { "schema_version": 1, "rail": "5V", "min_v": 4.8, "max_v": 5.2 }
    },
    {
      "order": 3,
      "step_type": "LED_SPECTRAL_READING",
      "name": "Check status LED",
      "hard_fail": false,
      "config_schema_version": 1,
      "config": {
        "schema_version": 1,
        "i2c_addr": "0x29",
        "mux_addr": "0x71",
        "mux_chan": "2",
        "r_min": 100, "r_max": 255
      }
    }
  ],
  "manual_checks": [
    { "order": 1, "text": "Confirm LED lights up green" }
  ]
}
```

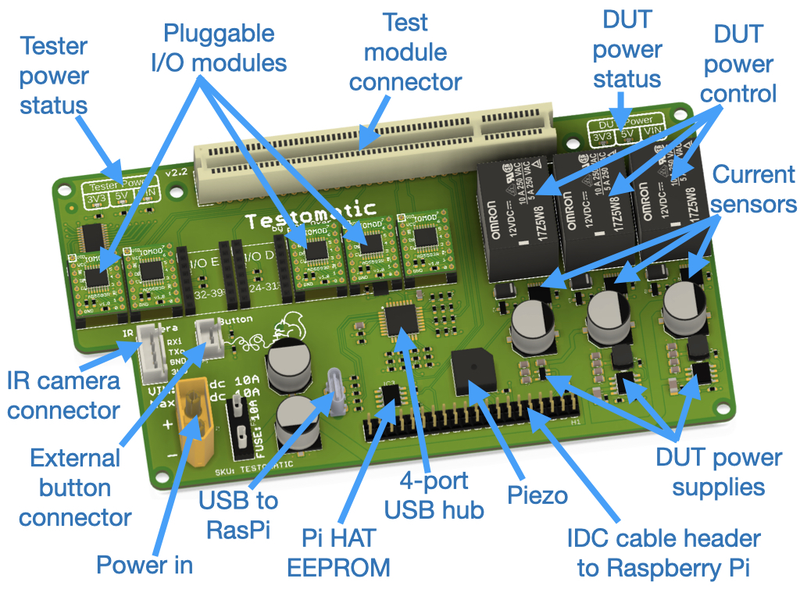
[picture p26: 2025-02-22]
Images/Testomatic-v2_2-PCB-annotated.jpeg

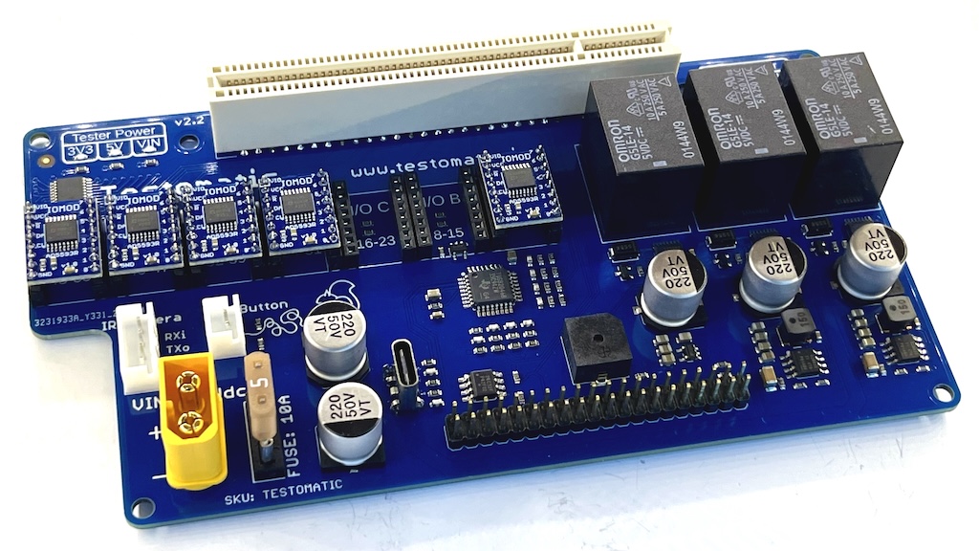
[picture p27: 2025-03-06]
Images/Testomatic-v2_2-pcb-oblique.jpg

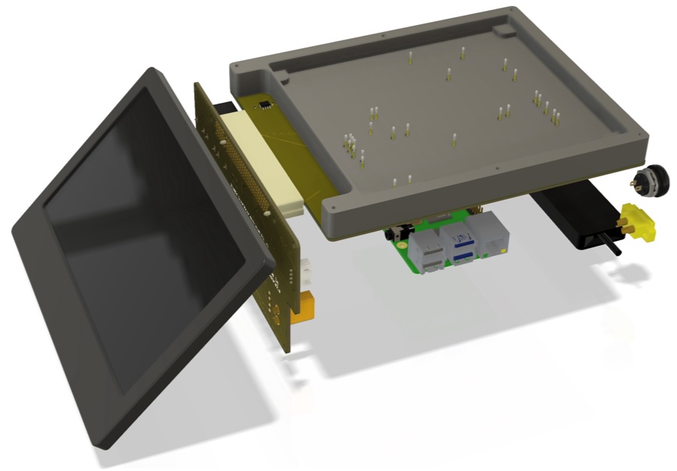
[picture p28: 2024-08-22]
Images/Testomatic-v2.jpeg

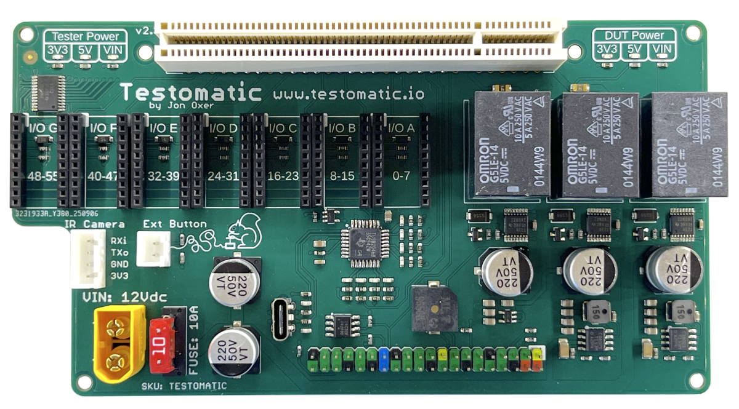
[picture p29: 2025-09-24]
Images/Testomatic-PCB-v2_3-top.png

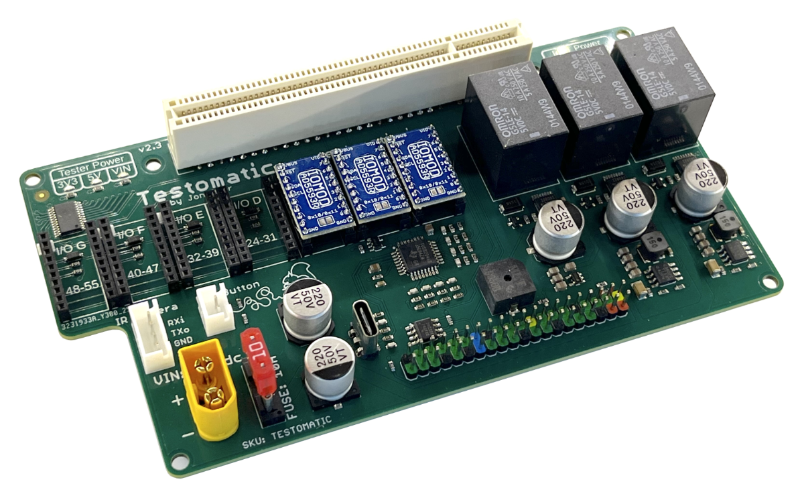
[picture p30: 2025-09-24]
Images/Testomatic-PCB-v2_3-oblique.png

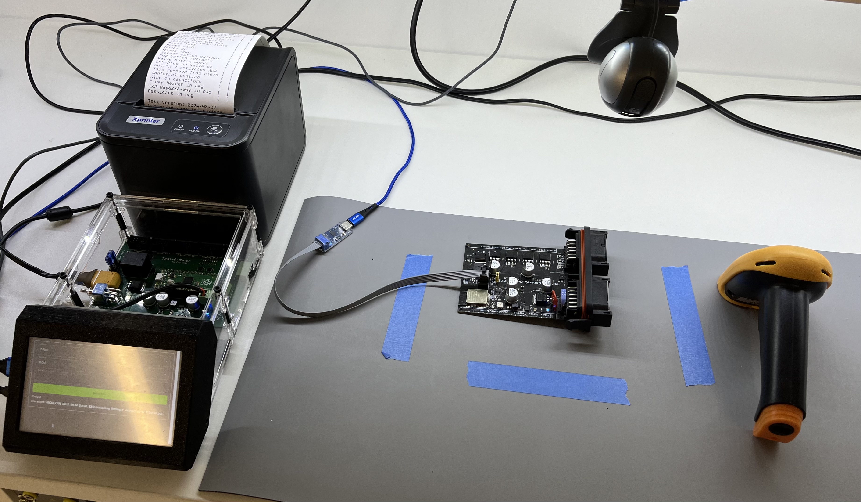
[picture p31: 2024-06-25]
Images/Test-jig.jpg

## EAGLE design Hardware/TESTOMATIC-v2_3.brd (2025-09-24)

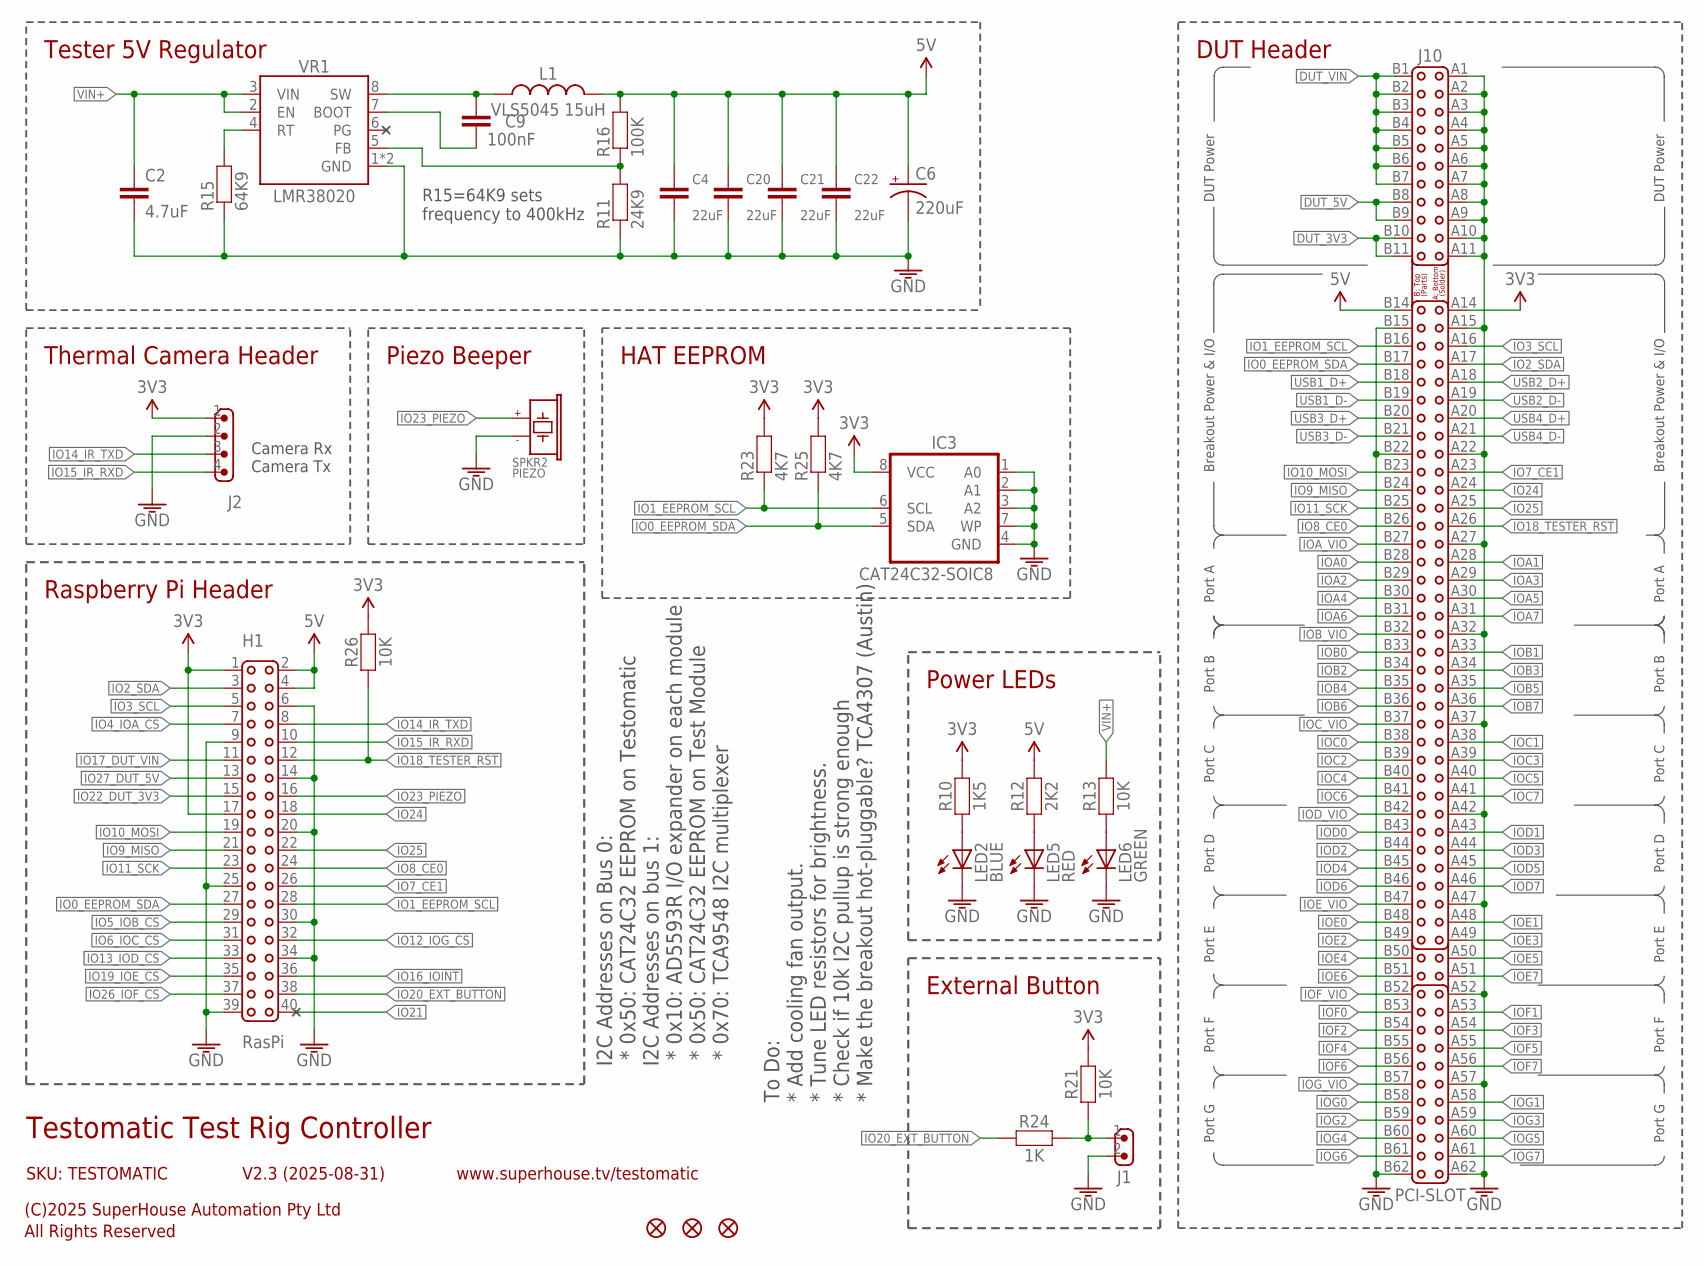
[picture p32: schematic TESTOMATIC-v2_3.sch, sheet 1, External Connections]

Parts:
C2: 4.7uF; C1206
C4, C20, C21, C22: 22uF; C0805
C6: 220uF; PANASONIC_G
C9: 100nF; C0603
FID1, FID2, FID3: FIDUCIAL1X2.5; FIDUCIAL-1X2.5
H1: RasPi; 2X20-P
IC3: CAT24C32-SOIC8; SOIC8
J1: M02-B2B-XH; JST-B2B-XH-A
J2: M04-B4B-XH; JST-B4B-XH-A
J10: PCI-SLOT
L1: VLS5045 15uH; INDUCTOR-5045
LED2: BLUE; LED-0603
LED5: RED; LED-0603
LED6: GREEN; LED-0603
R10: 1K5; R0603
R11: 24K9; R0603
R12: 2K2; R0603
R13, R21, R26: 10K; R0603
R15: 64K9; R0603
R16: 100K; R0603
R23, R25: 4K7; R0603
R24: 1K; R0603
SPKR2: PIEZO; PIEZO-9.6X9.6-SMT
VR1: LMR38020; HSOIC8

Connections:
3.3V: H1.1, H1.17, IC3.8 (VCC), J2.1, J10.A14, R10.2, R21.2, R23.2, R25.2, R26.2; also elsewhere on the board
5V: C4.1, C6.+, C20.1, C21.1, C22.1, H1.2, H1.4, J10.B14, L1.2, R12.2, R16.2; also elsewhere on the board
DUT_3V3: J10.B10, J10.B11; also elsewhere on the board
DUT_5V: J10.B8, J10.B9; also elsewhere on the board
DUT_VIN: J10.B1, J10.B2, J10.B3, J10.B4, J10.B5, J10.B6, J10.B7; also elsewhere on the board
GND: C2.2, C4.2, C6.-, C20.2, C21.2, C22.2, H1.6, H1.9, H1.14, H1.20, H1.25, H1.30, H1.34, H1.39, IC3.1 (A0), IC3.2 (A1), IC3.3 (A2), IC3.4 (GND), IC3.7 (WP), J1.2, J2.2, J10.A1, J10.A2, J10.A3, J10.A4, J10.A5, J10.A6, J10.A7, J10.A8, J10.A9, J10.A10, J10.A11, J10.A15, J10.A22, J10.A27, J10.A32, J10.A37, J10.A42, J10.A47, J10.A52, J10.A57, J10.A62, J10.B15, J10.B22, J10.B62, LED2.C, LED5.C, LED6.C, R11.1, R15.1, SPKR2.2 (-), VR1.1 (GND), VR1.TGND (GND); also elsewhere on the board
IO0_EEPROM_SDA: H1.27, IC3.5 (SDA), J10.B17, R25.1
IO1_EEPROM_SCL: H1.28, IC3.6 (SCL), J10.B16, R23.1
IO2_SDA: H1.3, J10.A17; also elsewhere on the board
IO3_SCL: H1.5, J10.A16; also elsewhere on the board
IO4_IOA_!CS: H1.7; also elsewhere on the board
IO5_IOB_!CS: H1.29; also elsewhere on the board
IO6_IOC_!CS: H1.31; also elsewhere on the board
IO7_CE1: H1.26, J10.A23
IO8_CE0: H1.24, J10.B26
IO9_MISO: H1.21, J10.B24; also elsewhere on the board
IO10_MOSI: H1.19, J10.B23; also elsewhere on the board
IO11_SCK: H1.23, J10.B25; also elsewhere on the board
IO12_IOG_!CS: H1.32; also elsewhere on the board
IO13_IOD_!CS: H1.33; also elsewhere on the board
IO14_IR_TXD: H1.8, J2.3
IO15_IR_RXD: H1.10, J2.4
IO16_IO!INT: H1.36; also elsewhere on the board
IO17_DUT_VIN: H1.11; also elsewhere on the board
IO18_!TESTER_RST: H1.12, J10.A26, R26.1; also elsewhere on the board
IO19_IOE_!CS: H1.35; also elsewhere on the board
IO20_EXT_BUTTON: H1.38, R24.1
IO21: H1.40
IO22_DUT_3V3: H1.15; also elsewhere on the board
IO23_PIEZO: H1.16, SPKR2.1 (+)
IO24: H1.18, J10.A24
IO25: H1.22, J10.A25
IO26_IOF_!CS: H1.37; also elsewhere on the board
IO27_DUT_5V: H1.13; also elsewhere on the board
IOA0: J10.B28; also elsewhere on the board
IOA1: J10.A28; also elsewhere on the board
IOA2: J10.B29; also elsewhere on the board
IOA3: J10.A29; also elsewhere on the board
IOA4: J10.B30; also elsewhere on the board
IOA5: J10.A30; also elsewhere on the board
IOA6: J10.B31; also elsewhere on the board
IOA7: J10.A31; also elsewhere on the board
IOA_VIO: J10.B27; also elsewhere on the board
IOB0: J10.B33; also elsewhere on the board
IOB1: J10.A33; also elsewhere on the board
IOB2: J10.B34; also elsewhere on the board
IOB3: J10.A34; also elsewhere on the board
IOB4: J10.B35; also elsewhere on the board
IOB5: J10.A35; also elsewhere on the board
IOB6: J10.B36; also elsewhere on the board
IOB7: J10.A36; also elsewhere on the board
IOB_VIO: J10.B32; also elsewhere on the board
IOC0: J10.B38; also elsewhere on the board
IOC1: J10.A38; also elsewhere on the board
IOC2: J10.B39; also elsewhere on the board
IOC3: J10.A39; also elsewhere on the board
IOC4: J10.B40; also elsewhere on the board
IOC5: J10.A40; also elsewhere on the board
IOC6: J10.B41; also elsewhere on the board
IOC7: J10.A41; also elsewhere on the board
IOC_VIO: J10.B37; also elsewhere on the board
IOD0: J10.B43; also elsewhere on the board
IOD1: J10.A43; also elsewhere on the board
IOD2: J10.B44; also elsewhere on the board
IOD3: J10.A44; also elsewhere on the board
IOD4: J10.B45; also elsewhere on the board
IOD5: J10.A45; also elsewhere on the board
IOD6: J10.B46; also elsewhere on the board
IOD7: J10.A46; also elsewhere on the board
IOD_VIO: J10.B42; also elsewhere on the board
IOE0: J10.B48; also elsewhere on the board
IOE1: J10.A48; also elsewhere on the board
IOE2: J10.B49; also elsewhere on the board
IOE3: J10.A49; also elsewhere on the board
IOE4: J10.B50; also elsewhere on the board
IOE5: J10.A50; also elsewhere on the board
IOE6: J10.B51; also elsewhere on the board
IOE7: J10.A51; also elsewhere on the board
IOE_VIO: J10.B47; also elsewhere on the board
IOF0: J10.B53; also elsewhere on the board
IOF1: J10.A53; also elsewhere on the board
IOF2: J10.B54; also elsewhere on the board
IOF3: J10.A54; also elsewhere on the board
IOF4: J10.B55; also elsewhere on the board
IOF5: J10.A55; also elsewhere on the board
IOF6: J10.B56; also elsewhere on the board
IOF7: J10.A56; also elsewhere on the board
IOF_VIO: J10.B52; also elsewhere on the board
IOG0: J10.B58; also elsewhere on the board
IOG1: J10.A58; also elsewhere on the board
IOG2: J10.B59; also elsewhere on the board
IOG3: J10.A59; also elsewhere on the board
IOG4: J10.B60; also elsewhere on the board
IOG5: J10.A60; also elsewhere on the board
IOG6: J10.B61; also elsewhere on the board
IOG7: J10.A61; also elsewhere on the board
IOG_VIO: J10.B57; also elsewhere on the board
unnamed: LED2.A, R10.1
unnamed: C9.1, L1.1, VR1.8 (SW)
unnamed: LED5.A, R12.1
unnamed: LED6.A, R13.1
unnamed: J1.1, R21.1, R24.2
unnamed: R15.2, VR1.4 (RT)
unnamed: R11.2, R16.1, VR1.5 (FB)
unnamed: C9.2, VR1.7 (BOOT)
PG: VR1.6 (PG); also elsewhere on the board
USB1_D+: J10.B18; also elsewhere on the board
USB1_D-: J10.B19; also elsewhere on the board
USB2_D+: J10.A18; also elsewhere on the board
USB2_D-: J10.A19; also elsewhere on the board
USB3_D+: J10.B20; also elsewhere on the board
USB3_D-: J10.B21; also elsewhere on the board
USB4_D+: J10.A20; also elsewhere on the board
USB4_D-: J10.A21; also elsewhere on the board
VIN+: C2.1, R13.2, VR1.2 (EN), VR1.3 (VIN); also elsewhere on the board

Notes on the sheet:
Testomatic Test Rig Controller
V2.3 (2025-08-31)
SKU: TESTOMATIC
(C)2025 SuperHouse Automation Pty Ltd
All Rights Reserved
www.superhouse.tv/testomatic
Tester 5V Regulator
R15=64K9 sets frequency to 400kHz
To Do: * Add cooling fan output. * Tune LED resistors for brightness. * Check if 10k I2C pullup is strong enough * Make the breakout hot-pluggable? TCA4307 (Austin)
Raspberry Pi Header
Thermal Camera Header
Camera Rx
Camera Tx
DUT Header
Piezo Beeper
DUT Power
Breakout Power & I/O
Port D
Power LEDs
External Button
HAT EEPROM
Port E
Port F
Port G
Port C
Port B
Port A
I2C Addresses on Bus 0: * 0x50: CAT24C32 EEPROM on Testomatic I2C Addresses on bus 1: * 0x10: AD5593R I/O expander on each module * 0x50: CAT24C32 EEPROM on Test Module * 0x70: TCA9548 I2C multiplexer

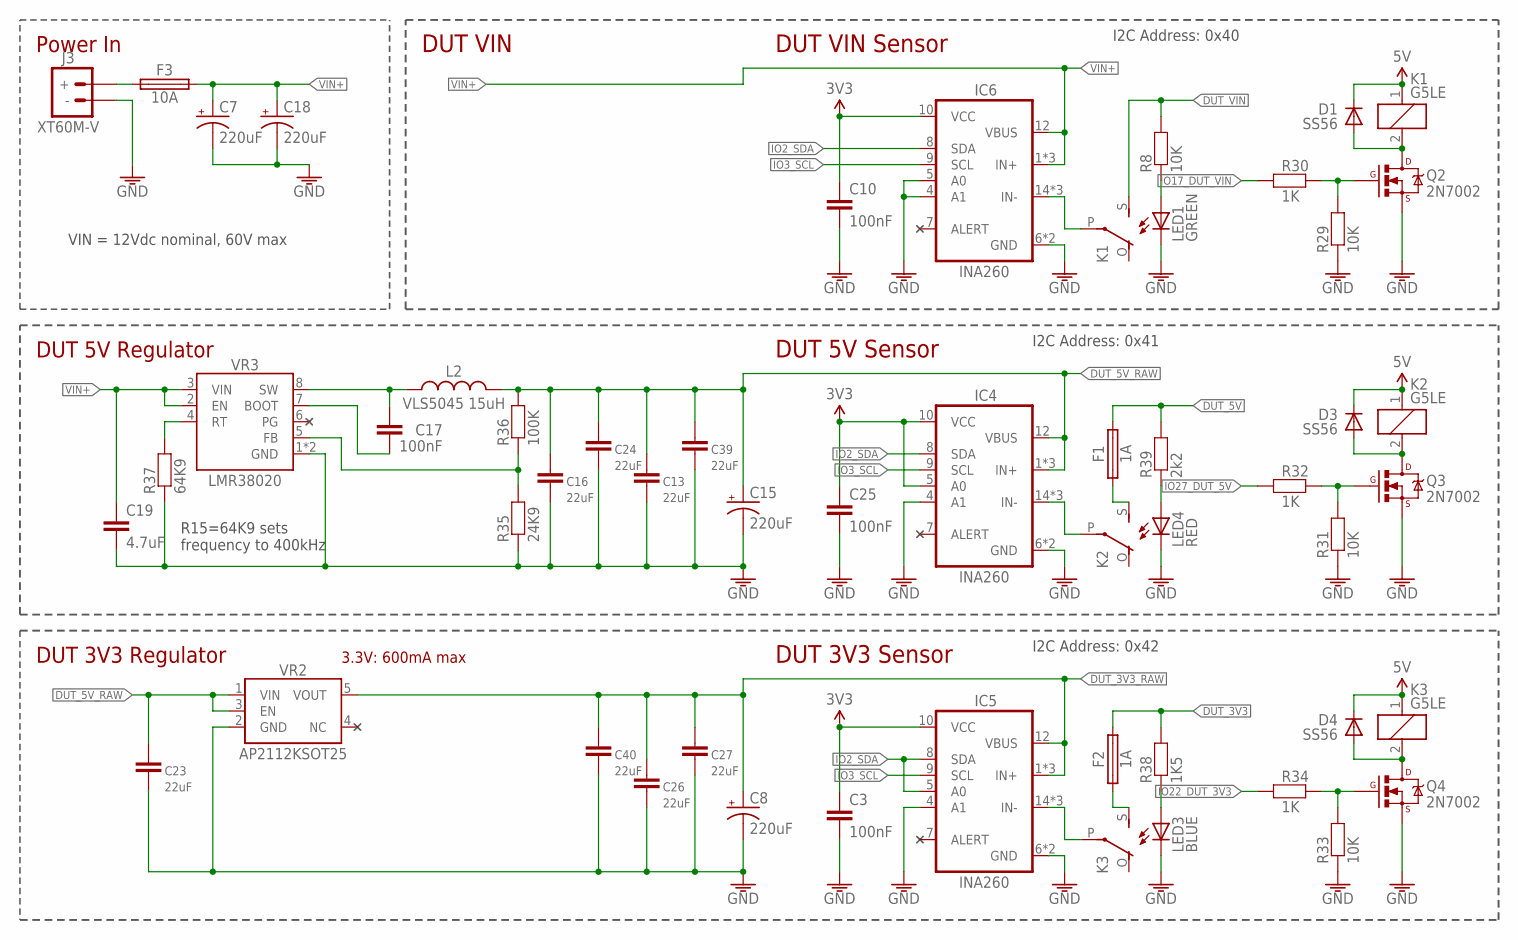
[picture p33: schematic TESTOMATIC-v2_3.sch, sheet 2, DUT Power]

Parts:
C3, C10, C17, C25: 100nF; C0603
C7, C8, C15, C18: 220uF; PANASONIC_G
C13, C16, C23, C24, C26, C27, C39, C40: 22uF; C0805
C19: 4.7uF; C1206
D1, D3, D4: SS56; SMA-DIODE
F1, F2: 1A; 1206
F3: 10A; MCCQ-122
IC4, IC5, IC6: INA260; TSSOP-16
J3: XT60M-V; XT60PW-M-V
K1, K2, K3: G5LE
L2: VLS5045 15uH; INDUCTOR-5045
LED1: GREEN; LED-0603
LED3: BLUE; LED-0603
LED4: RED; LED-0603
Q2, Q3, Q4: 2N7002; SOT23-3
R8, R29, R31, R33: 10K; R0603
R30, R32, R34: 1K; R0603
R35: 24K9; R0603
R36: 100K; R0603
R37: 64K9; R0603
R38: 1K5; R0603
R39: 2k2; R0603
VR2: AP2112KSOT25; SOT23-5
VR3: LMR38020; HSOIC8

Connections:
3.3V: C3.1, C10.1, C25.1, IC4.5 (A0), IC4.10 (VCC), IC5.10 (VCC), IC6.10 (VCC); also elsewhere on the board
5V: D1.C, D3.C, D4.C, K1.1, K2.1, K3.1; also elsewhere on the board
DUT_3V3: F2.2, R38.2; also elsewhere on the board
DUT_3V3_RAW: C8.+, C26.1, C27.1, C40.1, IC5.1 (IN+), IC5.2 (IN+), IC5.3 (IN+), IC5.12 (VBUS), VR2.5 (VOUT)
DUT_5V: F1.2, R39.2; also elsewhere on the board
DUT_5V_RAW: C13.1, C15.+, C16.1, C23.1, C24.1, C39.1, IC4.1 (IN+), IC4.2 (IN+), IC4.3 (IN+), IC4.12 (VBUS), L2.2, R36.2, VR2.1 (VIN), VR2.3 (EN)
DUT_VIN: K1.S (NO), R8.2; also elsewhere on the board
GND: C3.2, C7.-, C8.-, C10.2, C13.2, C15.-, C16.2, C18.-, C19.2, C23.2, C24.2, C25.2, C26.2, C27.2, C39.2, C40.2, IC4.4 (A1), IC4.6 (GND), IC4.11 (GND), IC5.4 (A1), IC5.6 (GND), IC5.11 (GND), IC6.4 (A1), IC6.5 (A0), IC6.6 (GND), IC6.11 (GND), J3.-, LED1.C, LED3.C, LED4.C, Q2.2 (S), Q3.2 (S), Q4.2 (S), R29.1, R31.1, R33.1, R35.1, R37.1, VR2.2 (GND), VR3.1 (GND), VR3.TGND (GND); also elsewhere on the board
IO2_SDA: IC4.8 (SDA), IC5.5 (A0), IC5.8 (SDA), IC6.8 (SDA); also elsewhere on the board
IO3_SCL: IC4.9 (SCL), IC5.9 (SCL), IC6.9 (SCL); also elsewhere on the board
IO17_DUT_VIN: R30.1; also elsewhere on the board
IO22_DUT_3V3: R34.1; also elsewhere on the board
IO27_DUT_5V: R32.1; also elsewhere on the board
unnamed: F3.1, F3.2 (1), J3.+
unnamed: D4.A, K3.2, Q4.3 (D)
unnamed: IC4.14 (IN-), IC4.15 (IN-), IC4.16 (IN-), K2.P (COM)
unnamed: IC6.14 (IN-), IC6.15 (IN-), IC6.16 (IN-), K1.P (COM)
unnamed: D1.A, K1.2, Q2.3 (D)
unnamed: LED1.A, R8.1
unnamed: Q2.1 (G), R29.2, R30.2
unnamed: F2.1, K3.S (NO)
unnamed: F1.1, K2.S (NO)
unnamed: D3.A, K2.2, Q3.3 (D)
unnamed: Q3.1 (G), R31.2, R32.2
unnamed: Q4.1 (G), R33.2, R34.2
unnamed: IC5.14 (IN-), IC5.15 (IN-), IC5.16 (IN-), K3.P (COM)
unnamed: C17.1, L2.1, VR3.8 (SW)
unnamed: R37.2, VR3.4 (RT)
unnamed: R35.2, R36.1, VR3.5 (FB)
unnamed: C17.2, VR3.7 (BOOT)
unnamed: LED4.A, R39.1
unnamed: LED3.A, R38.1
PG: VR3.6 (PG); also elsewhere on the board
VIN+: C7.+, C18.+, C19.1, F3.3 (2), F3.4 (2), IC6.1 (IN+), IC6.2 (IN+), IC6.3 (IN+), IC6.12 (VBUS), VR3.2 (EN), VR3.3 (VIN); also elsewhere on the board

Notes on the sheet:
DUT VIN Sensor
I2C Address: 0x40
DUT 5V Sensor
I2C Address: 0x41
DUT 3V3 Sensor
I2C Address: 0x42
3.3V: 600mA max
DUT 3V3 Regulator
DUT 5V Regulator
R15=64K9 sets frequency to 400kHz
DUT VIN
VIN = 12Vdc nominal, 60V max
Power In

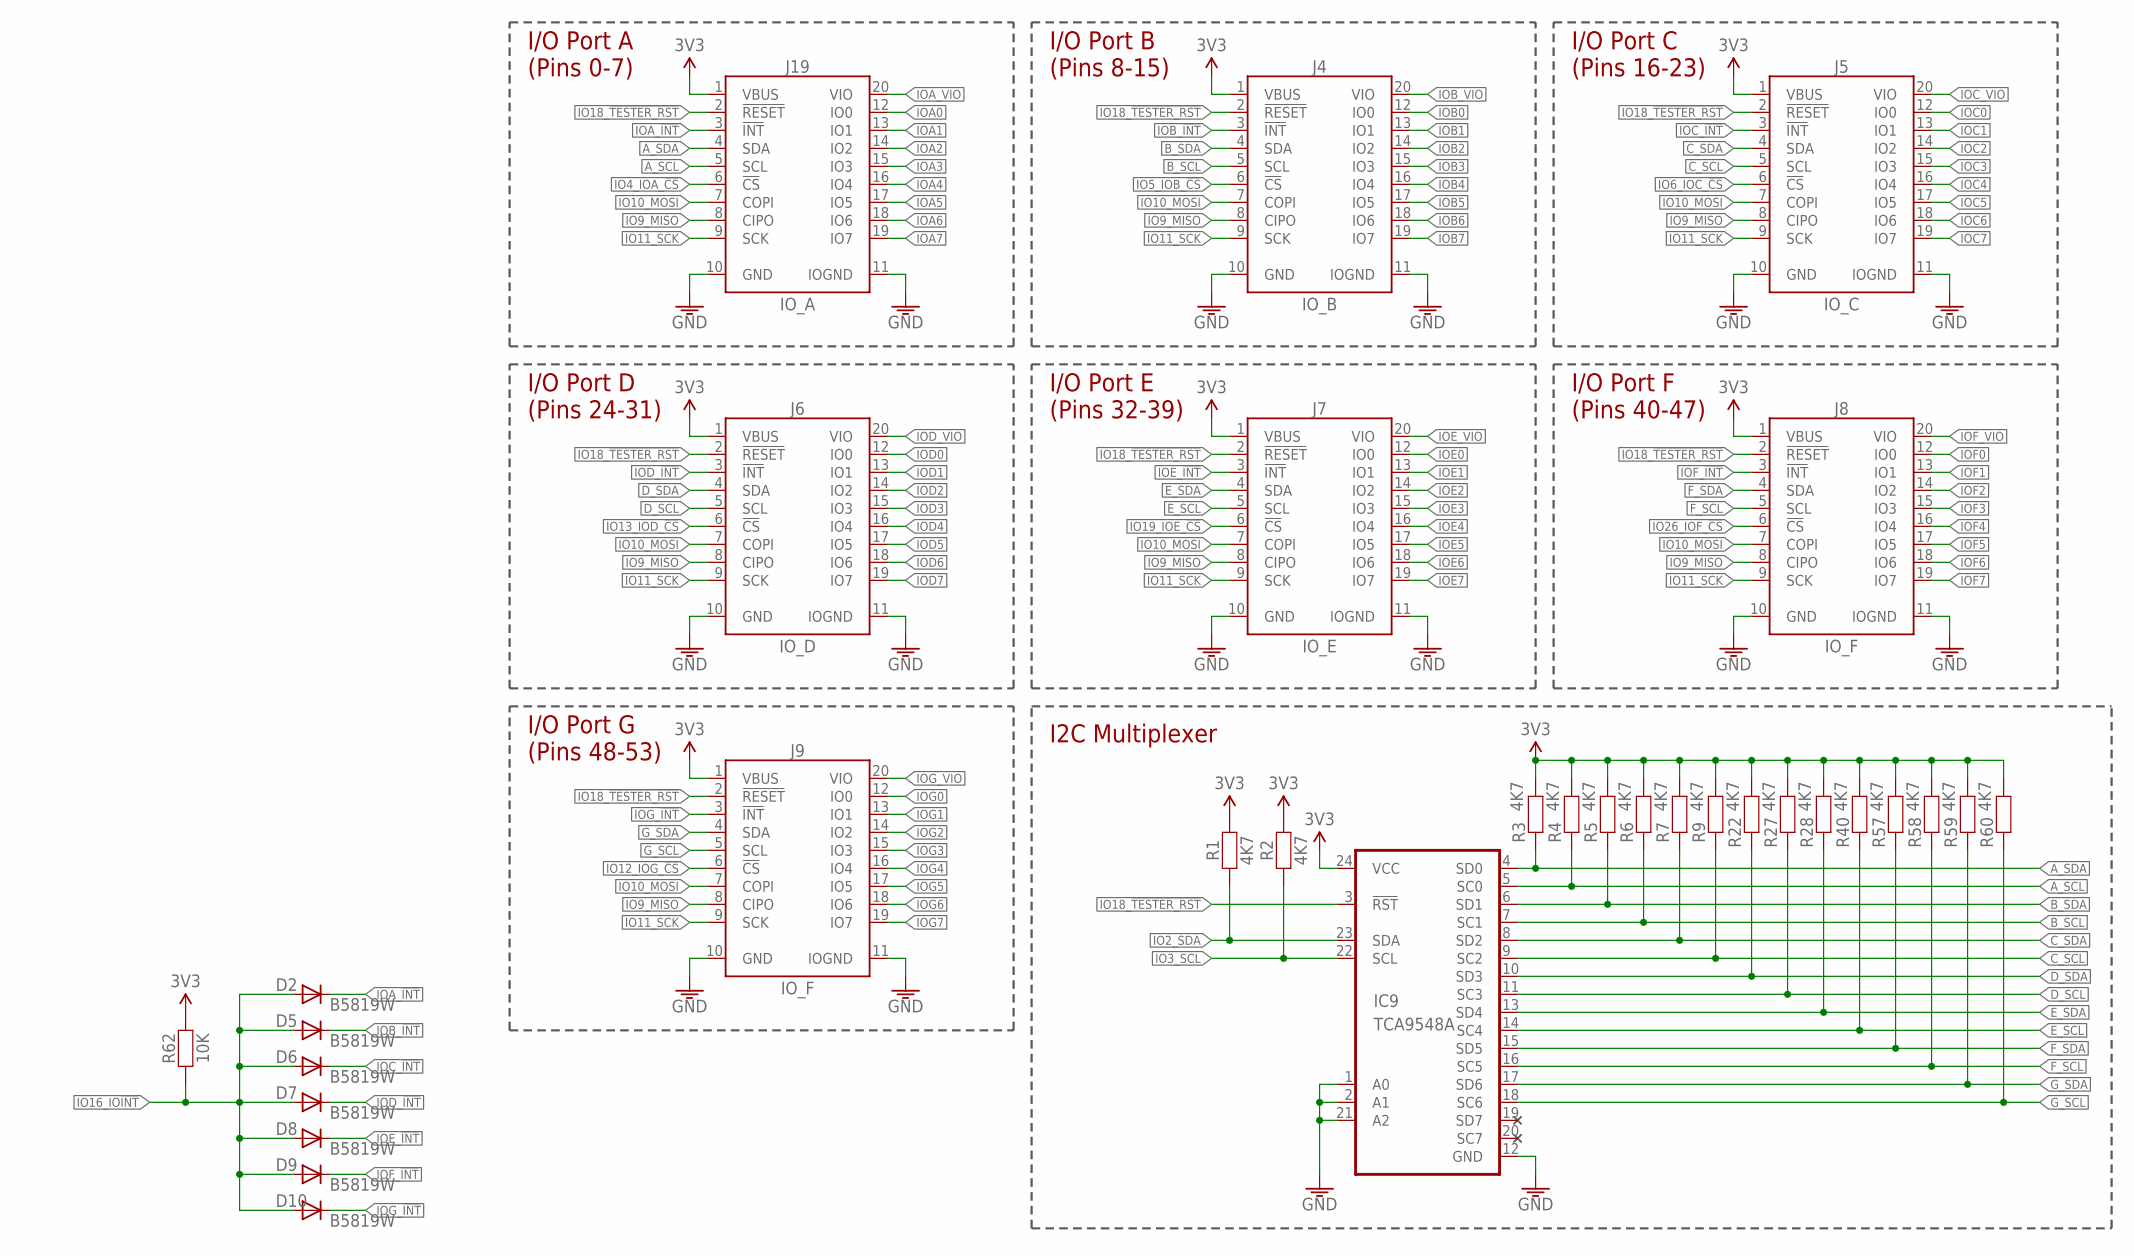
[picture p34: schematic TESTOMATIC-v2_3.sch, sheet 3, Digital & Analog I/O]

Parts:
D2, D5, D6, D7, D8, D9, D10: B5819W; SOD-123
IC9: TCA9548A; TSSOP24
J4: IO_B; IOMOD
J5: IO_C; IOMOD
J6: IO_D; IOMOD
J7: IO_E; IOMOD
J8, J9: IO_F; IOMOD
J19: IO_A; IOMOD
R1, R2, R3, R4, R5, R6, R7, R9, R22, R27, R28, R40, R57, R58, R59, R60: 4K7; R0603
R62: 10K; R0603

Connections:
3.3V: IC9.24 (VCC), J4.1 (VBUS), J5.1 (VBUS), J6.1 (VBUS), J7.1 (VBUS), J8.1 (VBUS), J9.1 (VBUS), J19.1 (VBUS), R1.2, R2.2, R3.2, R4.2, R5.2, R6.2, R7.2, R9.2, R22.2, R27.2, R28.2, R40.2, R57.2, R58.2, R59.2, R60.2, R62.2; also elsewhere on the board
A_SCL: IC9.5 (SC0), J19.5 (SCL), R4.1
A_SDA: IC9.4 (SD0), J19.4 (SDA), R3.1
B_SCL: IC9.7 (SC1), J4.5 (SCL), R6.1
B_SDA: IC9.6 (SD1), J4.4 (SDA), R5.1
C_SCL: IC9.9 (SC2), J5.5 (SCL), R9.1
C_SDA: IC9.8 (SD2), J5.4 (SDA), R7.1
D_SCL: IC9.11 (SC3), J6.5 (SCL), R27.1
D_SDA: IC9.10 (SD3), J6.4 (SDA), R22.1
E_SCL: IC9.14 (SC4), J7.5 (SCL), R40.1
E_SDA: IC9.13 (SD4), J7.4 (SDA), R28.1
F_SCL: IC9.16 (SC5), J8.5 (SCL), R58.1
F_SDA: IC9.15 (SD5), J8.4 (SDA), R57.1
GND: IC9.1 (A0), IC9.2 (A1), IC9.12 (GND), IC9.21 (A2), J4.10 (GND), J4.11 (IOGND), J5.10 (GND), J5.11 (IOGND), J6.10 (GND), J6.11 (IOGND), J7.10 (GND), J7.11 (IOGND), J8.10 (GND), J8.11 (IOGND), J9.10 (GND), J9.11 (IOGND), J19.10 (GND), J19.11 (IOGND); also elsewhere on the board
G_SCL: IC9.18 (SC6), J9.5 (SCL), R60.1
G_SDA: IC9.17 (SD6), J9.4 (SDA), R59.1
IO2_SDA: IC9.23 (SDA), R1.1; also elsewhere on the board
IO3_SCL: IC9.22 (SCL), R2.1; also elsewhere on the board
IO4_IOA_!CS: J19.6 (!CS); also elsewhere on the board
IO5_IOB_!CS: J4.6 (!CS); also elsewhere on the board
IO6_IOC_!CS: J5.6 (!CS); also elsewhere on the board
IO9_MISO: J4.8 (CIPO), J5.8 (CIPO), J6.8 (CIPO), J7.8 (CIPO), J8.8 (CIPO), J9.8 (CIPO), J19.8 (CIPO); also elsewhere on the board
IO10_MOSI: J4.7 (COPI), J5.7 (COPI), J6.7 (COPI), J7.7 (COPI), J8.7 (COPI), J9.7 (COPI), J19.7 (COPI); also elsewhere on the board
IO11_SCK: J4.9 (SCK), J5.9 (SCK), J6.9 (SCK), J7.9 (SCK), J8.9 (SCK), J9.9 (SCK), J19.9 (SCK); also elsewhere on the board
IO12_IOG_!CS: J9.6 (!CS); also elsewhere on the board
IO13_IOD_!CS: J6.6 (!CS); also elsewhere on the board
IO16_IO!INT: D2.2 (A), D5.2 (A), D6.2 (A), D7.2 (A), D8.2 (A), D9.2 (A), D10.2 (A), R62.1; also elsewhere on the board
IO18_!TESTER_RST: IC9.3 (!RST), J4.2 (!RESET), J5.2 (!RESET), J6.2 (!RESET), J7.2 (!RESET), J8.2 (!RESET), J9.2 (!RESET), J19.2 (!RESET); also elsewhere on the board
IO19_IOE_!CS: J7.6 (!CS); also elsewhere on the board
IO26_IOF_!CS: J8.6 (!CS); also elsewhere on the board
IOA0: J19.12 (IO0); also elsewhere on the board
IOA1: J19.13 (IO1); also elsewhere on the board
IOA2: J19.14 (IO2); also elsewhere on the board
IOA3: J19.15 (IO3); also elsewhere on the board
IOA4: J19.16 (IO4); also elsewhere on the board
IOA5: J19.17 (IO5); also elsewhere on the board
IOA6: J19.18 (IO6); also elsewhere on the board
IOA7: J19.19 (IO7); also elsewhere on the board
IOA_!INT: D2.1 (C), J19.3 (!INT)
IOA_VIO: J19.20 (VIO); also elsewhere on the board
IOB0: J4.12 (IO0); also elsewhere on the board
IOB1: J4.13 (IO1); also elsewhere on the board
IOB2: J4.14 (IO2); also elsewhere on the board
IOB3: J4.15 (IO3); also elsewhere on the board
IOB4: J4.16 (IO4); also elsewhere on the board
IOB5: J4.17 (IO5); also elsewhere on the board
IOB6: J4.18 (IO6); also elsewhere on the board
IOB7: J4.19 (IO7); also elsewhere on the board
IOB_!INT: D5.1 (C), J4.3 (!INT)
IOB_VIO: J4.20 (VIO); also elsewhere on the board
IOC0: J5.12 (IO0); also elsewhere on the board
IOC1: J5.13 (IO1); also elsewhere on the board
IOC2: J5.14 (IO2); also elsewhere on the board
IOC3: J5.15 (IO3); also elsewhere on the board
IOC4: J5.16 (IO4); also elsewhere on the board
IOC5: J5.17 (IO5); also elsewhere on the board
IOC6: J5.18 (IO6); also elsewhere on the board
IOC7: J5.19 (IO7); also elsewhere on the board
IOC_!INT: D6.1 (C), J5.3 (!INT)
IOC_VIO: J5.20 (VIO); also elsewhere on the board
IOD0: J6.12 (IO0); also elsewhere on the board
IOD1: J6.13 (IO1); also elsewhere on the board
IOD2: J6.14 (IO2); also elsewhere on the board
IOD3: J6.15 (IO3); also elsewhere on the board
IOD4: J6.16 (IO4); also elsewhere on the board
IOD5: J6.17 (IO5); also elsewhere on the board
IOD6: J6.18 (IO6); also elsewhere on the board
IOD7: J6.19 (IO7); also elsewhere on the board
IOD_!INT: D7.1 (C), J6.3 (!INT)
IOD_VIO: J6.20 (VIO); also elsewhere on the board
IOE0: J7.12 (IO0); also elsewhere on the board
IOE1: J7.13 (IO1); also elsewhere on the board
IOE2: J7.14 (IO2); also elsewhere on the board
IOE3: J7.15 (IO3); also elsewhere on the board
IOE4: J7.16 (IO4); also elsewhere on the board
IOE5: J7.17 (IO5); also elsewhere on the board
IOE6: J7.18 (IO6); also elsewhere on the board
IOE7: J7.19 (IO7); also elsewhere on the board
IOE_!INT: D8.1 (C), J7.3 (!INT)
IOE_VIO: J7.20 (VIO); also elsewhere on the board
IOF0: J8.12 (IO0); also elsewhere on the board
IOF1: J8.13 (IO1); also elsewhere on the board
IOF2: J8.14 (IO2); also elsewhere on the board
IOF3: J8.15 (IO3); also elsewhere on the board
IOF4: J8.16 (IO4); also elsewhere on the board
IOF5: J8.17 (IO5); also elsewhere on the board
IOF6: J8.18 (IO6); also elsewhere on the board
IOF7: J8.19 (IO7); also elsewhere on the board
IOF_!INT: D9.1 (C), J8.3 (!INT)
IOF_VIO: J8.20 (VIO); also elsewhere on the board
IOG0: J9.12 (IO0); also elsewhere on the board
IOG1: J9.13 (IO1); also elsewhere on the board
IOG2: J9.14 (IO2); also elsewhere on the board
IOG3: J9.15 (IO3); also elsewhere on the board
IOG4: J9.16 (IO4); also elsewhere on the board
IOG5: J9.17 (IO5); also elsewhere on the board
IOG6: J9.18 (IO6); also elsewhere on the board
IOG7: J9.19 (IO7); also elsewhere on the board
IOG_!INT: D10.1 (C), J9.3 (!INT)
IOG_VIO: J9.20 (VIO); also elsewhere on the board

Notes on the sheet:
I/O Port A (Pins 0-7)
I2C Multiplexer
I/O Port B (Pins 8-15)
I/O Port C (Pins 16-23)
I/O Port D (Pins 24-31)
I/O Port E (Pins 32-39)
I/O Port F (Pins 40-47)
I/O Port G (Pins 48-53)

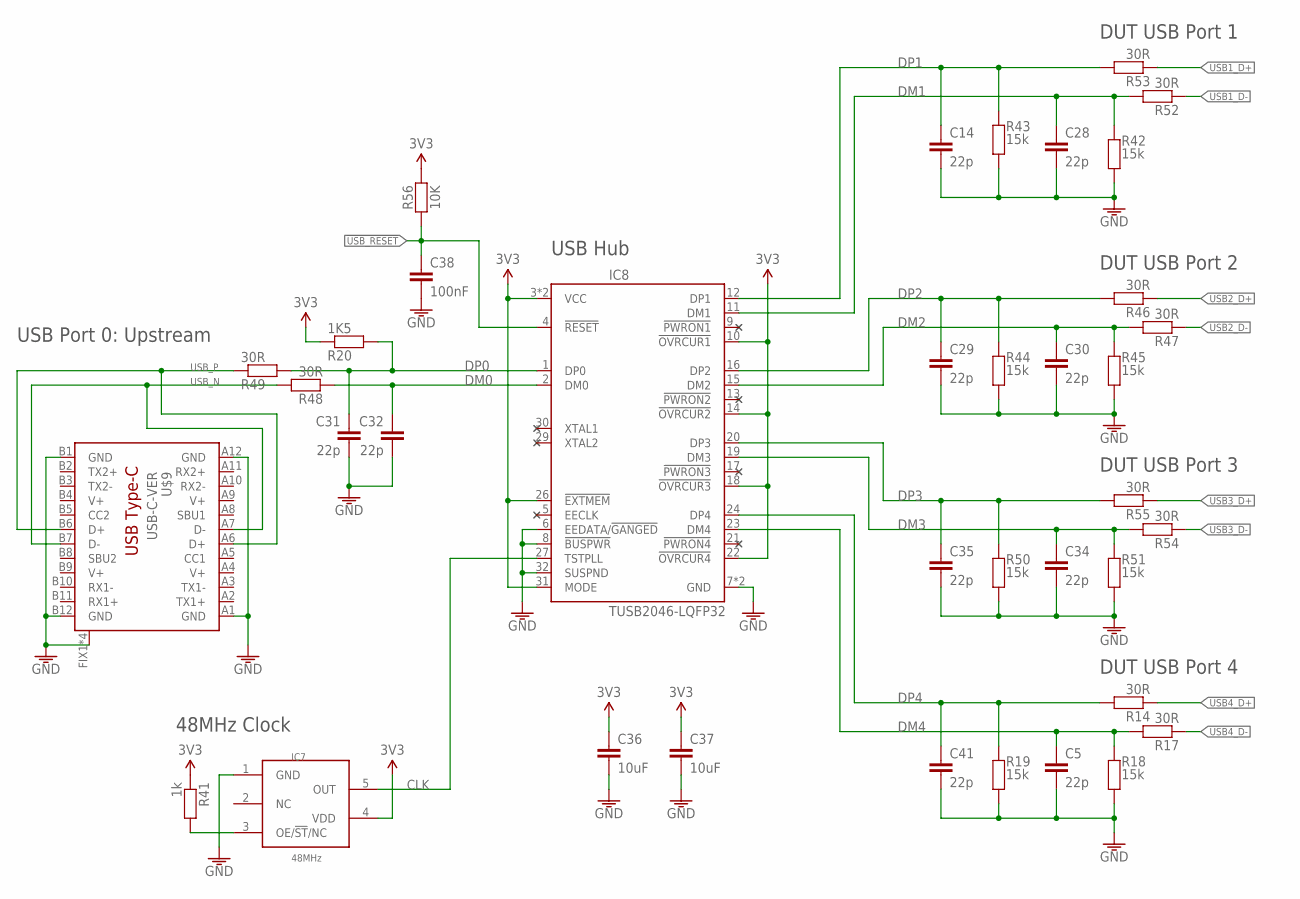
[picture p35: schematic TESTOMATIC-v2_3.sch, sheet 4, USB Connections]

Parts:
C5, C14, C28, C29, C30, C31, C32, C34, C35, C41: 22p; C0603
C36, C37: 10uF; C0805
C38: 100nF; C0603
IC7: 48MHz; SOT-23-5
IC8: TUSB2046-LQFP32; LQFP32
R14, R17, R46, R47, R48, R49, R52, R53, R54, R55: 30R; R0603
R18, R19, R42, R43, R44, R45, R50, R51: 15k; R0603
R20: 1K5; R0603
R41: 1k; R0603
R56: 10K; R0603
U$9: USB-C-VER; USB-C-VERT

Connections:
3.3V: C36.1, C37.1, IC7.4 (VDD), IC8.3 (VCC), IC8.10 (!OVRCUR1), IC8.14 (!OVRCUR2), IC8.18 (!OVRCUR3), IC8.22 (!OVRCUR4), IC8.25 (VCC), IC8.26 (!EXTMEM), IC8.31 (MODE), R20.1, R41.1, R56.2; also elsewhere on the board
!USB_RESET: C38.1, IC8.4 (!RESET), R56.1
CLK: IC7.5 (OUT), IC8.27 (TSTPLL)
DM0: C32.1, IC8.2 (DM0), R48.2
DM1: C28.1, IC8.11 (DM1), R42.1, R52.2
DM2: C30.1, IC8.15 (DM2), R45.1, R47.2
DM3: C34.1, IC8.19 (DM3), R51.1, R54.2
DM4: C5.1, IC8.23 (DM4), R17.2, R18.1
DP0: C31.1, IC8.1 (DP0), R20.2, R49.2
DP1: C14.1, IC8.12 (DP1), R43.1, R53.2
DP2: C29.1, IC8.16 (DP2), R44.1, R46.2
DP3: C35.1, IC8.20 (DP3), R50.1, R55.2
DP4: C41.1, IC8.24 (DP4), R14.2, R19.1
GND: C5.2, C14.2, C28.2, C29.2, C30.2, C31.2, C32.2, C34.2, C35.2, C36.2, C37.2, C38.2, C41.2, IC7.1 (GND), IC8.6 (EEDATA/!GANGED), IC8.7 (GND), IC8.8 (!BUSPWR), IC8.28 (GND), IC8.32 (SUSPND), R18.2, R19.2, R42.2, R43.2, R44.2, R45.2, R50.2, R51.2, U$9.A1 (GND), U$9.A12 (GND), U$9.B1 (GND), U$9.B12 (GND), U$9.FIX1 (CASE), U$9.FIX2 (CASE), U$9.FIX3 (CASE), U$9.FIX4 (CASE); also elsewhere on the board
unnamed: IC7.3 (OE/!ST!/NC), R41.2
USB1_D+: R53.1; also elsewhere on the board
USB1_D-: R52.1; also elsewhere on the board
USB2_D+: R46.1; also elsewhere on the board
USB2_D-: R47.1; also elsewhere on the board
USB3_D+: R55.1; also elsewhere on the board
USB3_D-: R54.1; also elsewhere on the board
USB4_D+: R14.1; also elsewhere on the board
USB4_D-: R17.1; also elsewhere on the board
USB_N: R48.1, U$9.A7 (D-), U$9.B7 (D-)
USB_P: R49.1, U$9.A6 (D+), U$9.B6 (D+)
V+: U$9.A4 (V+), U$9.A9 (V+), U$9.B4 (V+), U$9.B9 (V+)

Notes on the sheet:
DUT USB Port 1
DUT USB Port 2
DUT USB Port 3
USB Hub
USB Port 0: Upstream
48MHz Clock
DUT USB Port 4

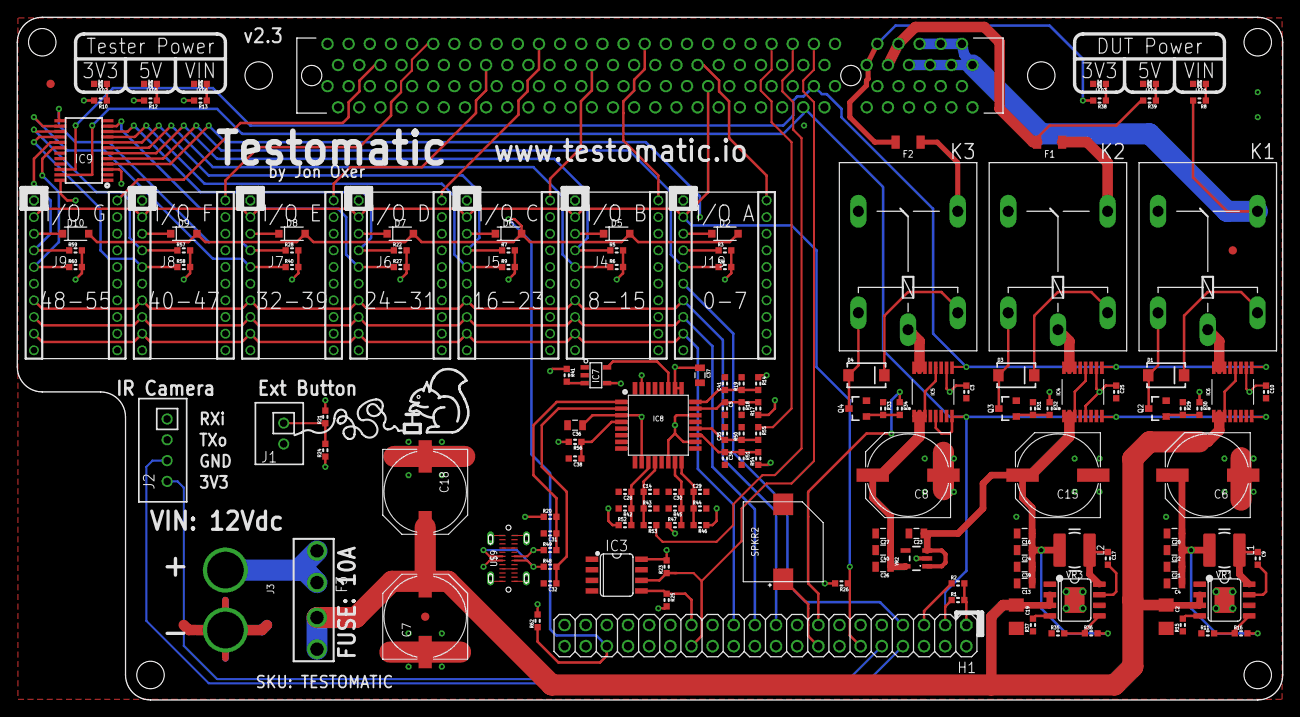
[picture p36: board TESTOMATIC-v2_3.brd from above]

Board: 6 copper layers, 152.0 x 82.0 mm, 152 parts (0 on the bottom side), 172 nets.

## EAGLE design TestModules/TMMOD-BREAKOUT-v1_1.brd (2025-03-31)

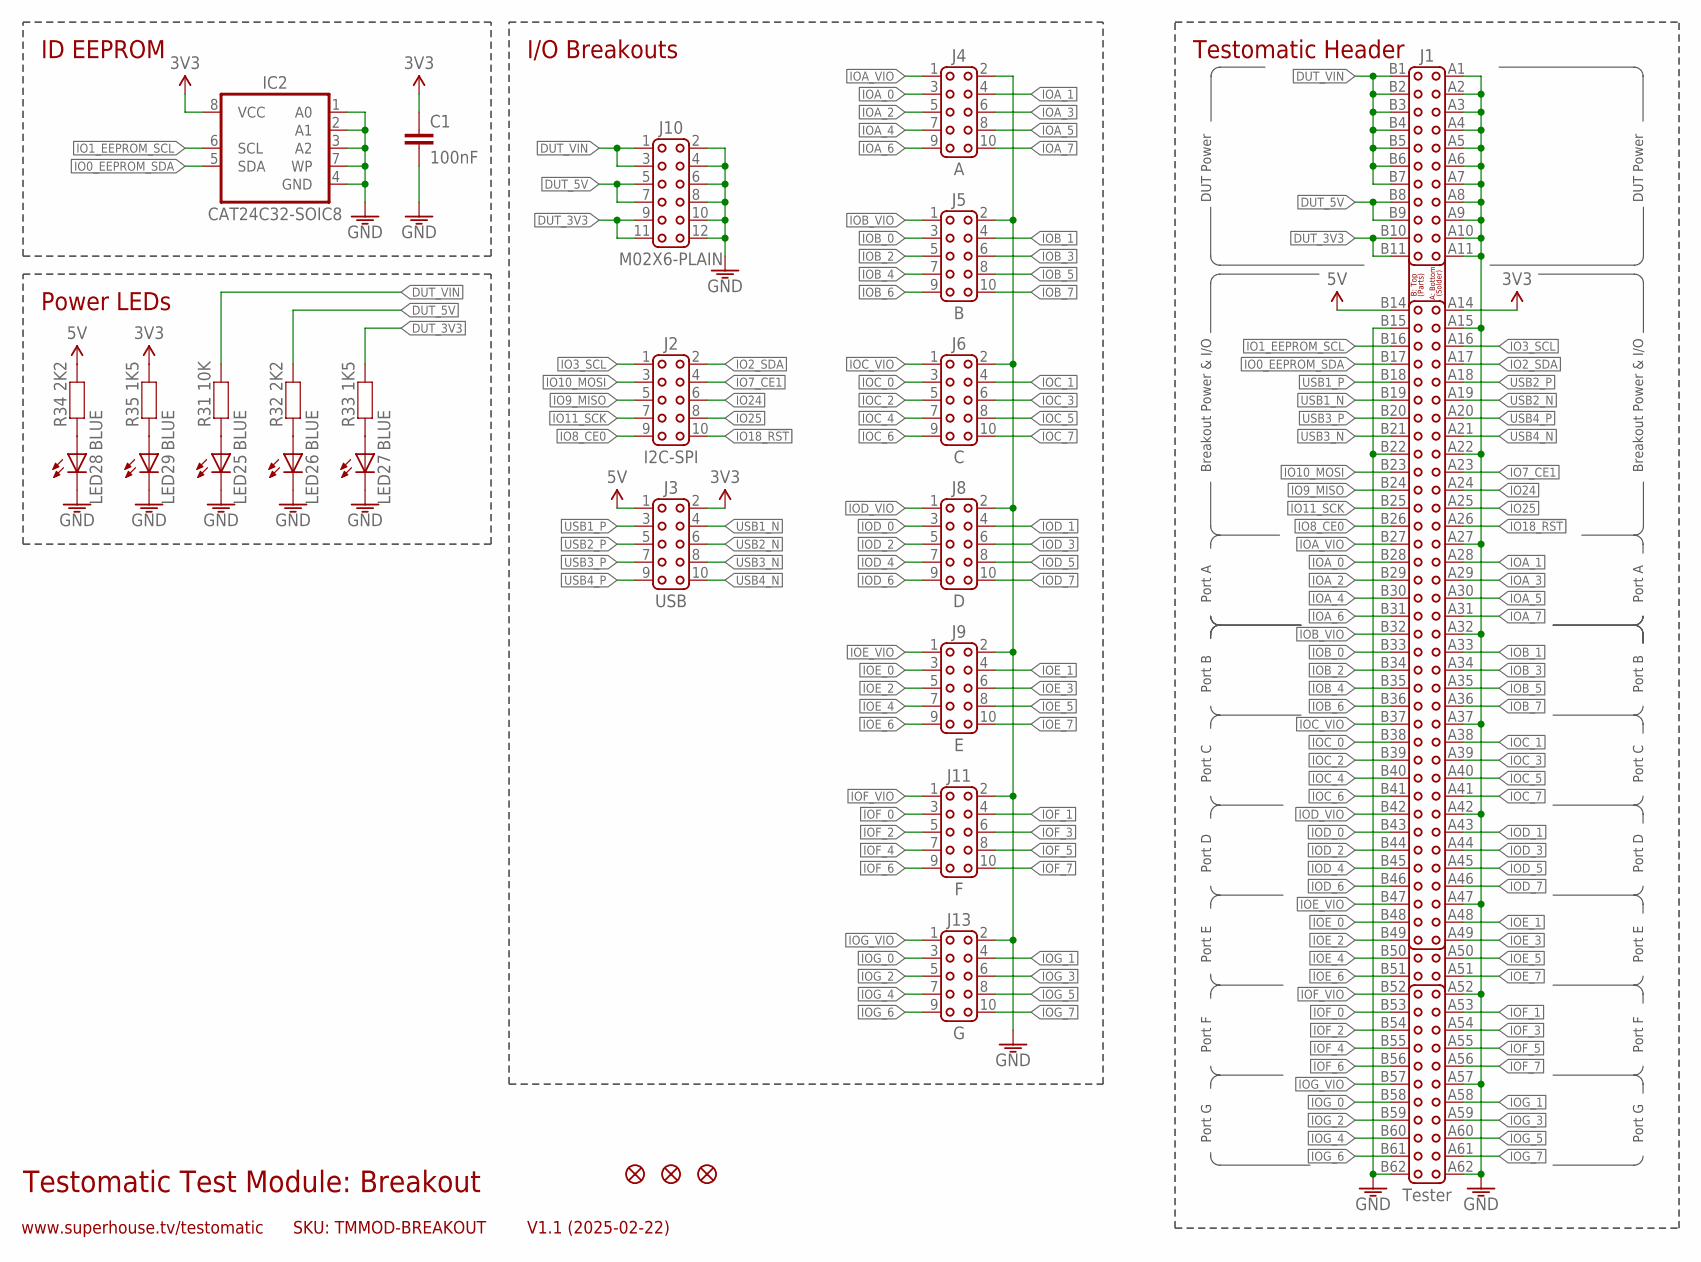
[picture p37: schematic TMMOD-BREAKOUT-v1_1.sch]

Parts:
C1: 100nF; C0603
FID1, FID2, FID3: FIDUCIAL1X2.5; FIDUCIAL-1X2.5
IC2: CAT24C32-SOIC8; SOIC8
J1: Tester; PCI-CARD
J2: I2C-SPI; 2X05-2.54-PLAIN
J3: USB; 2X05-2.54-PLAIN
J4: A; 2X05-2.54-PLAIN
J5: B; 2X05-2.54-PLAIN
J6: C; 2X05-2.54-PLAIN
J8: D; 2X05-2.54-PLAIN
J9: E; 2X05-2.54-PLAIN
J10: M02X6-PLAIN; 2X06
J11: F; 2X05-2.54-PLAIN
J13: G; 2X05-2.54-PLAIN
LED25, LED26, LED27, LED28, LED29: BLUE; LED-0603
R31: 10K; R0603
R32, R34: 2K2; R0603
R33, R35: 1K5; R0603

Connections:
3.3V: C1.1, IC2.8 (VCC), J1.A14, J3.2, R35.2
5V: J1.B14, J3.1, R34.2
DUT_3V3: J1.B10, J1.B11, J10.9, J10.11, R33.2
DUT_5V: J1.B8, J1.B9, J10.5, J10.7, R32.2
DUT_VIN: J1.B1, J1.B2, J1.B3, J1.B4, J1.B5, J1.B6, J1.B7, J10.1, J10.3, R31.2
GND: C1.2, IC2.1 (A0), IC2.2 (A1), IC2.3 (A2), IC2.4 (GND), IC2.7 (WP), J1.A1, J1.A2, J1.A3, J1.A4, J1.A5, J1.A6, J1.A7, J1.A8, J1.A9, J1.A10, J1.A11, J1.A15, J1.A22, J1.A27, J1.A32, J1.A37, J1.A42, J1.A47, J1.A52, J1.A57, J1.A62, J1.B15, J1.B22, J1.B62, J4.2, J5.2, J6.2, J8.2, J9.2, J10.2, J10.4, J10.6, J10.8, J10.10, J10.12, J11.2, J13.2, LED25.C, LED26.C, LED27.C, LED28.C, LED29.C
IO0_EEPROM_SDA: IC2.5 (SDA), J1.B17
IO1_EEPROM_SCL: IC2.6 (SCL), J1.B16
IO2_SDA: J1.A17, J2.2
IO3_SCL: J1.A16, J2.1
IO7_CE1: J1.A23, J2.4
IO8_CE0: J1.B26, J2.9
IO9_MISO: J1.B24, J2.5
IO10_MOSI: J1.B23, J2.3
IO11_SCK: J1.B25, J2.7
IO18_!RST: J1.A26, J2.10
IO24: J1.A24, J2.6
IO25: J1.A25, J2.8
IOA_0: J1.B28, J4.3
IOA_1: J1.A28, J4.4
IOA_2: J1.B29, J4.5
IOA_3: J1.A29, J4.6
IOA_4: J1.B30, J4.7
IOA_5: J1.A30, J4.8
IOA_6: J1.B31, J4.9
IOA_7: J1.A31, J4.10
IOA_VIO: J1.B27, J4.1
IOB_0: J1.B33, J5.3
IOB_1: J1.A33, J5.4
IOB_2: J1.B34, J5.5
IOB_3: J1.A34, J5.6
IOB_4: J1.B35, J5.7
IOB_5: J1.A35, J5.8
IOB_6: J1.B36, J5.9
IOB_7: J1.A36, J5.10
IOB_VIO: J1.B32, J5.1
IOC_0: J1.B38, J6.3
IOC_1: J1.A38, J6.4
IOC_2: J1.B39, J6.5
IOC_3: J1.A39, J6.6
IOC_4: J1.B40, J6.7
IOC_5: J1.A40, J6.8
IOC_6: J1.B41, J6.9
IOC_7: J1.A41, J6.10
IOC_VIO: J1.B37, J6.1
IOD_0: J1.B43, J8.3
IOD_1: J1.A43, J8.4
IOD_2: J1.B44, J8.5
IOD_3: J1.A44, J8.6
IOD_4: J1.B45, J8.7
IOD_5: J1.A45, J8.8
IOD_6: J1.B46, J8.9
IOD_7: J1.A46, J8.10
IOD_VIO: J1.B42, J8.1
IOE_0: J1.B48, J9.3
IOE_1: J1.A48, J9.4
IOE_2: J1.B49, J9.5
IOE_3: J1.A49, J9.6
IOE_4: J1.B50, J9.7
IOE_5: J1.A50, J9.8
IOE_6: J1.B51, J9.9
IOE_7: J1.A51, J9.10
IOE_VIO: J1.B47, J9.1
IOF_0: J1.B53, J11.3
IOF_1: J1.A53, J11.4
IOF_2: J1.B54, J11.5
IOF_3: J1.A54, J11.6
IOF_4: J1.B55, J11.7
IOF_5: J1.A55, J11.8
IOF_6: J1.B56, J11.9
IOF_7: J1.A56, J11.10
IOF_VIO: J1.B52, J11.1
IOG_0: J1.B58, J13.3
IOG_1: J1.A58, J13.4
IOG_2: J1.B59, J13.5
IOG_3: J1.A59, J13.6
IOG_4: J1.B60, J13.7
IOG_5: J1.A60, J13.8
IOG_6: J1.B61, J13.9
IOG_7: J1.A61, J13.10
IOG_VIO: J1.B57, J13.1
unnamed: LED25.A, R31.1
unnamed: LED28.A, R34.1
unnamed: LED26.A, R32.1
unnamed: LED27.A, R33.1
unnamed: LED29.A, R35.1
USB1_N: J1.B19, J3.4
USB1_P: J1.B18, J3.3
USB2_N: J1.A19, J3.6
USB2_P: J1.A18, J3.5
USB3_N: J1.B21, J3.8
USB3_P: J1.B20, J3.7
USB4_N: J1.A21, J3.10
USB4_P: J1.A20, J3.9

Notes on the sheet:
Testomatic Test Module: Breakout
V1.1 (2025-02-22)
www.superhouse.tv/testomatic
SKU: TMMOD-BREAKOUT
ID EEPROM
Testomatic Header
DUT Power
Breakout Power & I/O
Power LEDs
I/O Breakouts
Port A
Port B
Port G
Port F
Port E
Port D
Port C

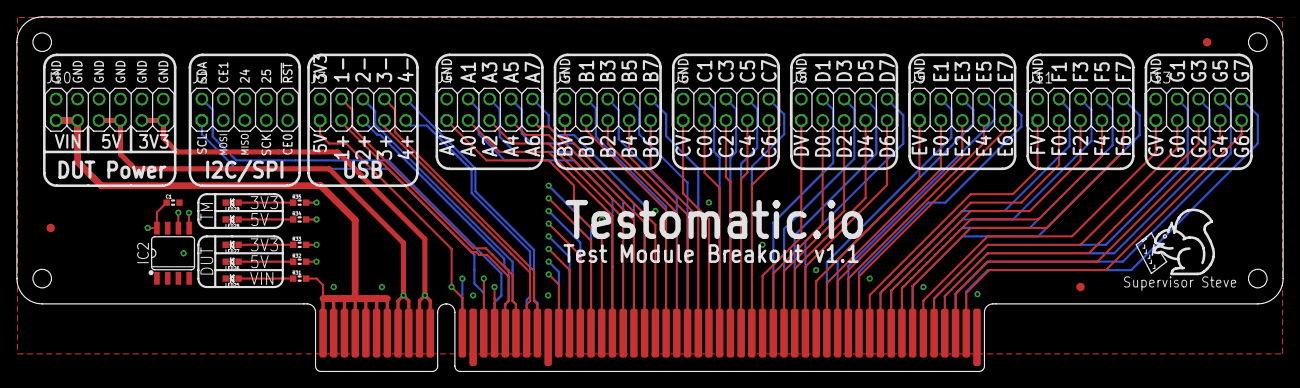
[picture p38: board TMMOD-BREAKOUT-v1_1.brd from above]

Board: 4 copper layers, 150.0 x 42.0 mm, 26 parts (0 on the bottom side), 94 nets.

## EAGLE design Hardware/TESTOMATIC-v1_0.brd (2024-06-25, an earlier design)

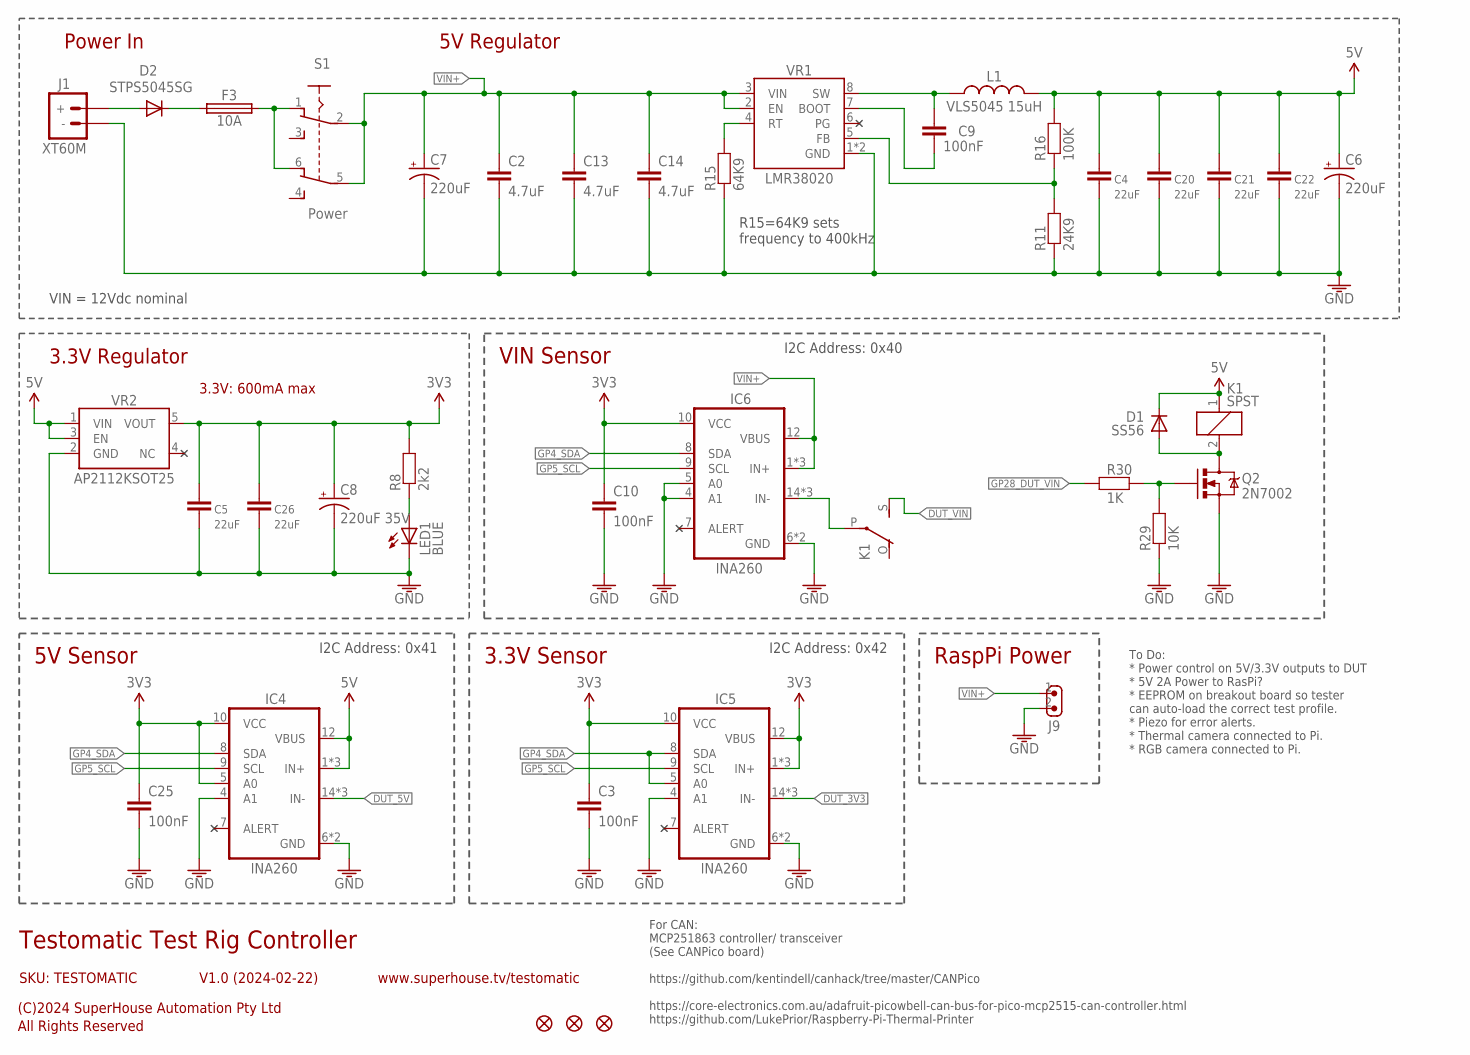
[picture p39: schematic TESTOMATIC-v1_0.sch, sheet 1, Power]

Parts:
C2, C13, C14: 4.7uF; C1206
C3, C9, C10, C25: 100nF; C0603
C4, C5, C20, C21, C22, C26: 22uF; C0805
C6, C7: 220uF; PANASONIC_G
C8: 220uF 35V; PANASONIC_G
D1: SS56; SMA-DIODE
D2: STPS5045SG; D2PACK
F3: 10A; MCCQ-122
FID1, FID2, FID3: FIDUCIAL1X2.5; FIDUCIAL-1X2.5
IC4, IC5, IC6: INA260; TSSOP-16
J1: XT60M; XT60PW-M
J9: M02-SCREW-3.81MM-VERT; SCREWTERMINAL-3.81MM-VERT-2
K1: SPST; G5LE
L1: VLS5045 15uH; INDUCTOR-5045
LED1: BLUE; LED-0603
Q2: 2N7002; SOT23-3
R8: 2k2; R0603
R11: 24K9; R0603
R15: 64K9; R0603
R16: 100K; R0603
R29: 10K; R0603
R30: 1K; R0603
S1: Power; 7201SD9AV2BE
VR1: LMR38020; HSOIC8
VR2: AP2112KSOT25; SOT23-5

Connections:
3.3V: C3.1, C5.1, C8.+, C10.1, C25.1, C26.1, IC4.5 (A0), IC4.10 (VCC), IC5.1 (IN+), IC5.2 (IN+), IC5.3 (IN+), IC5.10 (VCC), IC5.12 (VBUS), IC6.10 (VCC), R8.2, VR2.5 (VOUT); also elsewhere on the board
5V: C4.1, C6.+, C20.1, C21.1, C22.1, D1.C, IC4.1 (IN+), IC4.2 (IN+), IC4.3 (IN+), IC4.12 (VBUS), K1.1, L1.2, R16.2, VR2.1 (VIN), VR2.3 (EN); also elsewhere on the board
DUT_3V3: IC5.14 (IN-), IC5.15 (IN-), IC5.16 (IN-); also elsewhere on the board
DUT_5V: IC4.14 (IN-), IC4.15 (IN-), IC4.16 (IN-); also elsewhere on the board
DUT_VIN: K1.S (NO); also elsewhere on the board
GND: C2.2, C3.2, C4.2, C5.2, C6.-, C7.-, C8.-, C10.2, C13.2, C14.2, C20.2, C21.2, C22.2, C25.2, C26.2, IC4.4 (A1), IC4.6 (GND), IC4.11 (GND), IC5.4 (A1), IC5.6 (GND), IC5.11 (GND), IC6.4 (A1), IC6.5 (A0), IC6.6 (GND), IC6.11 (GND), J1.-, J9.2, LED1.C, Q2.2 (S), R11.1, R15.1, R29.1, VR1.1 (GND), VR1.TGND (GND), VR2.2 (GND); also elsewhere on the board
GP4_SDA: IC4.8 (SDA), IC5.5 (A0), IC5.8 (SDA), IC6.8 (SDA); also elsewhere on the board
GP5_SCL: IC4.9 (SCL), IC5.9 (SCL), IC6.9 (SCL); also elsewhere on the board
GP28_DUT_VIN: R30.1; also elsewhere on the board
unnamed: C9.1, L1.1, VR1.8 (SW)
unnamed: D2.2 (C), F3.1, F3.2 (1)
unnamed: R15.2, VR1.4 (RT)
unnamed: IC6.14 (IN-), IC6.15 (IN-), IC6.16 (IN-), K1.P (COM)
unnamed: D1.A, K1.2, Q2.3 (D)
unnamed: R11.2, R16.1, VR1.5 (FB)
unnamed: C9.2, VR1.7 (BOOT)
unnamed: LED1.A, R8.1
unnamed: Q2.1 (G), R29.2, R30.2
unnamed: F3.3 (2), F3.4 (2), S1.1, S1.6
unnamed: D2.1 (A), D2.3 (A), J1.+
PG: VR1.6 (PG)
VIN+: C2.1, C7.+, C13.1, C14.1, IC6.1 (IN+), IC6.2 (IN+), IC6.3 (IN+), IC6.12 (VBUS), J9.1, S1.2, S1.5, VR1.2 (EN), VR1.3 (VIN)

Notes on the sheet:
Testomatic Test Rig Controller
V1.0 (2024-02-22)
SKU: TESTOMATIC
(C)2024 SuperHouse Automation Pty Ltd
All Rights Reserved
www.superhouse.tv/testomatic
3.3V: 600mA max
VIN = 12Vdc nominal
5V Regulator
3.3V Regulator
Power In
R15=64K9 sets frequency to 400kHz
5V Sensor
I2C Address: 0x41
3.3V Sensor
I2C Address: 0x42
VIN Sensor
I2C Address: 0x40
For CAN: MCP251863 controller/ transceiver (See CANPico board) https://github.com/kentindell/canhack/tree/master/CANPico https://core-electronics.com.au/adafruit-picowbell-can-bus-for-pico-mcp2515-can-controller.html https://github.com/LukePrior/Raspberry-Pi-Thermal-Printer
To Do: * Power control on 5V/3.3V outputs to DUT * 5V 2A Power to RasPi? * EEPROM on breakout board so tester can auto-load the correct test profile. * Piezo for error alerts. * Thermal camera connected to Pi. * RGB camera connected to Pi.
RaspPi Power

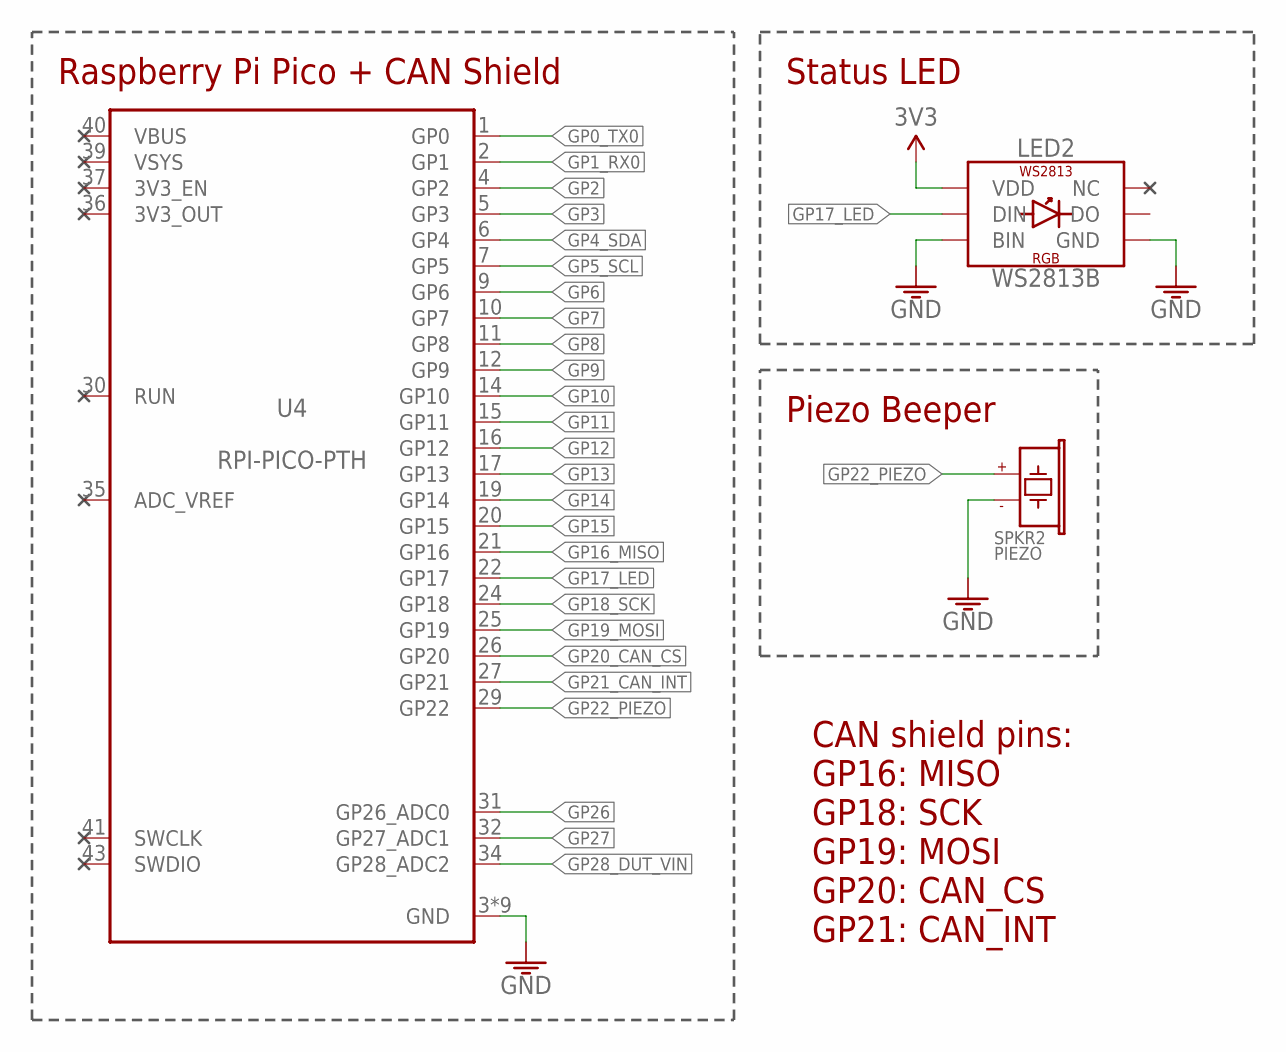
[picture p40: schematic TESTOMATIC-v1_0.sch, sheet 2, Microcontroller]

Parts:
LED2: WS2813B; WS2813
SPKR2: PIEZO; PIEZO-9.6X9.6-SMT
U4: RPI-PICO-PTH; PICO-PTH

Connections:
3.3V: LED2.2 (VDD); also elsewhere on the board
GND: LED2.5 (GND), LED2.6 (BIN), SPKR2.2 (-), U4.3 (GND), U4.8 (GND), U4.13 (GND), U4.18 (GND), U4.23 (GND), U4.28 (GND), U4.33 (GND), U4.38 (GND), U4.42 (GND); also elsewhere on the board
GP0_TX0: U4.1 (GP0); also elsewhere on the board
GP1_RX0: U4.2 (GP1); also elsewhere on the board
GP2: U4.4 (GP2); also elsewhere on the board
GP3: U4.5 (GP3); also elsewhere on the board
GP4_SDA: U4.6 (GP4); also elsewhere on the board
GP5_SCL: U4.7 (GP5); also elsewhere on the board
GP6: U4.9 (GP6); also elsewhere on the board
GP7: U4.10 (GP7); also elsewhere on the board
GP8: U4.11 (GP8); also elsewhere on the board
GP9: U4.12 (GP9); also elsewhere on the board
GP10: U4.14 (GP10); also elsewhere on the board
GP11: U4.15 (GP11); also elsewhere on the board
GP12: U4.16 (GP12); also elsewhere on the board
GP13: U4.17 (GP13); also elsewhere on the board
GP14: U4.19 (GP14); also elsewhere on the board
GP15: U4.20 (GP15); also elsewhere on the board
GP16_MISO: U4.21 (GP16)
GP17_LED: LED2.4 (DIN), U4.22 (GP17)
GP18_SCK: U4.24 (GP18)
GP19_MOSI: U4.25 (GP19)
GP20_CAN_CS: U4.26 (GP20)
GP21_CAN_INT: U4.27 (GP21)
GP22_PIEZO: SPKR2.1 (+), U4.29 (GP22)
GP26: U4.31 (GP26_ADC0); also elsewhere on the board
GP27: U4.32 (GP27_ADC1); also elsewhere on the board
GP28_DUT_VIN: U4.34 (GP28_ADC2); also elsewhere on the board
VBUS: U4.40 (VBUS)

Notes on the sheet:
Piezo Beeper
Status LED
CAN shield pins: GP16: MISO GP18: SCK GP19: MOSI GP20: CAN_CS GP21: CAN_INT
Raspberry Pi Pico + CAN Shield

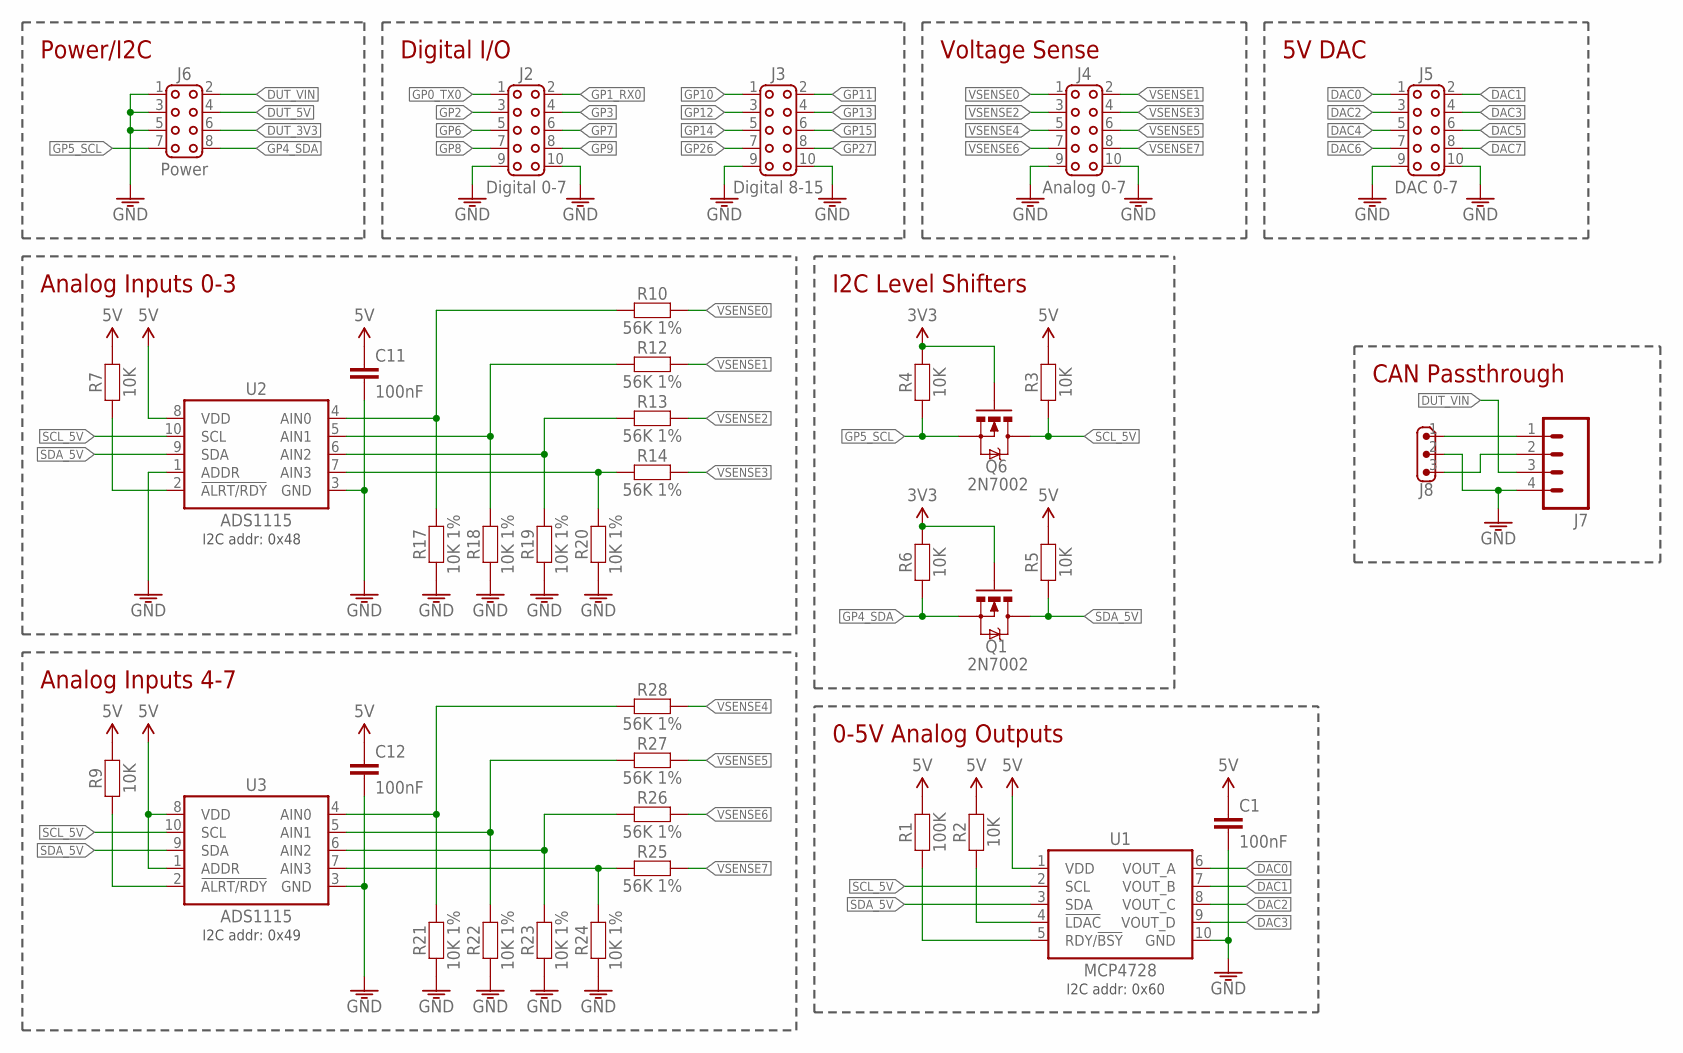
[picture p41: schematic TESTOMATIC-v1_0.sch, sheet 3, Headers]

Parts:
C1, C11, C12: 100nF; C0603
J2: Digital 0-7; 2X05-2.54-SHROUDED
J3: Digital 8-15; 2X05-2.54-SHROUDED
J4: Analog 0-7; 2X05-2.54-SHROUDED
J5: DAC 0-7; 2X05-2.54-SHROUDED
J6: Power; 2X04-2.54-SHROUDED
J7: M04-SCREW-3.81MM-VERT-PLUG; SCREWTERMINAL-3.81MM-VERT-4
J8: M03-SCREW-3.5MM; SCREWTERMINAL-3.5MM-3
Q1, Q6: 2N7002; SOT23-3
R1: 100K; R0603
R2, R3, R4, R5, R6, R7, R9: 10K; R0603
R10, R12, R13, R14, R25, R26, R27, R28: 56K 1%; R0603
R17, R18, R19, R20, R21, R22, R23, R24: 10K 1%; R0603
U1: MCP4728; MSOP10
U2, U3: ADS1115; MSOP10

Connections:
3.3V: Q1.1 (G), Q6.1 (G), R4.2, R6.2; also elsewhere on the board
5V: C1.1, C11.1, C12.1, R1.2, R2.2, R3.2, R5.2, R7.2, R9.2, U1.1 (VDD), U2.8 (VDD), U3.1 (ADDR), U3.8 (VDD); also elsewhere on the board
DAC0: J5.1, U1.6 (VOUT_A)
DAC1: J5.2, U1.7 (VOUT_B)
DAC2: J5.3, U1.8 (VOUT_C)
DAC3: J5.4, U1.9 (VOUT_D)
DAC4: J5.5
DAC5: J5.6
DAC6: J5.7
DAC7: J5.8
DUT_3V3: J6.6; also elsewhere on the board
DUT_5V: J6.4; also elsewhere on the board
DUT_VIN: J6.2, J7.3; also elsewhere on the board
GND: C1.2, C11.2, C12.2, J2.9, J2.10, J3.9, J3.10, J4.9, J4.10, J5.9, J5.10, J6.1, J6.3, J6.5, J7.4, J8.2, R17.1, R18.1, R19.1, R20.1, R21.1, R22.1, R23.1, R24.1, U1.10 (GND), U2.1 (ADDR), U2.3 (GND), U3.3 (GND); also elsewhere on the board
GP0_TX0: J2.1; also elsewhere on the board
GP1_RX0: J2.2; also elsewhere on the board
GP2: J2.3; also elsewhere on the board
GP3: J2.4; also elsewhere on the board
GP4_SDA: J6.8, Q1.2 (S), R6.1; also elsewhere on the board
GP5_SCL: J6.7, Q6.2 (S), R4.1; also elsewhere on the board
GP6: J2.5; also elsewhere on the board
GP7: J2.6; also elsewhere on the board
GP8: J2.7; also elsewhere on the board
GP9: J2.8; also elsewhere on the board
GP10: J3.1; also elsewhere on the board
GP11: J3.2; also elsewhere on the board
GP12: J3.3; also elsewhere on the board
GP13: J3.4; also elsewhere on the board
GP14: J3.5; also elsewhere on the board
GP15: J3.6; also elsewhere on the board
GP26: J3.7; also elsewhere on the board
GP27: J3.8; also elsewhere on the board
unnamed: R7.1, U2.2 (!ALRT/RDY)
unnamed: R10.1, R17.2, U2.4 (AIN0)
unnamed: R12.1, R18.2, U2.5 (AIN1)
unnamed: R13.1, R19.2, U2.6 (AIN2)
unnamed: R14.1, R20.2, U2.7 (AIN3)
unnamed: R21.2, R28.1, U3.4 (AIN0)
unnamed: R22.2, R27.1, U3.5 (AIN1)
unnamed: R23.2, R26.1, U3.6 (AIN2)
unnamed: R24.2, R25.1, U3.7 (AIN3)
unnamed: R9.1, U3.2 (!ALRT/RDY)
unnamed: J7.1, J8.1
unnamed: J7.2, J8.3
unnamed: R2.1, U1.4 (!LDAC)
unnamed: R1.1, U1.5 (RDY/!BSY)
SCL_5V: Q6.3 (D), R3.1, U1.2 (SCL), U2.10 (SCL), U3.10 (SCL)
SDA_5V: Q1.3 (D), R5.1, U1.3 (SDA), U2.9 (SDA), U3.9 (SDA)
VSENSE0: J4.1, R10.2
VSENSE1: J4.2, R12.2
VSENSE2: J4.3, R13.2
VSENSE3: J4.4, R14.2
VSENSE4: J4.5, R28.2
VSENSE5: J4.6, R27.2
VSENSE6: J4.7, R26.2
VSENSE7: J4.8, R25.2

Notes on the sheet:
Power/I2C
Digital I/O
Voltage Sense
5V DAC
I2C Level Shifters
0-5V Analog Outputs
Analog Inputs 0-3
I2C addr: 0x48
I2C addr: 0x49
I2C addr: 0x60
Analog Inputs 4-7
CAN Passthrough

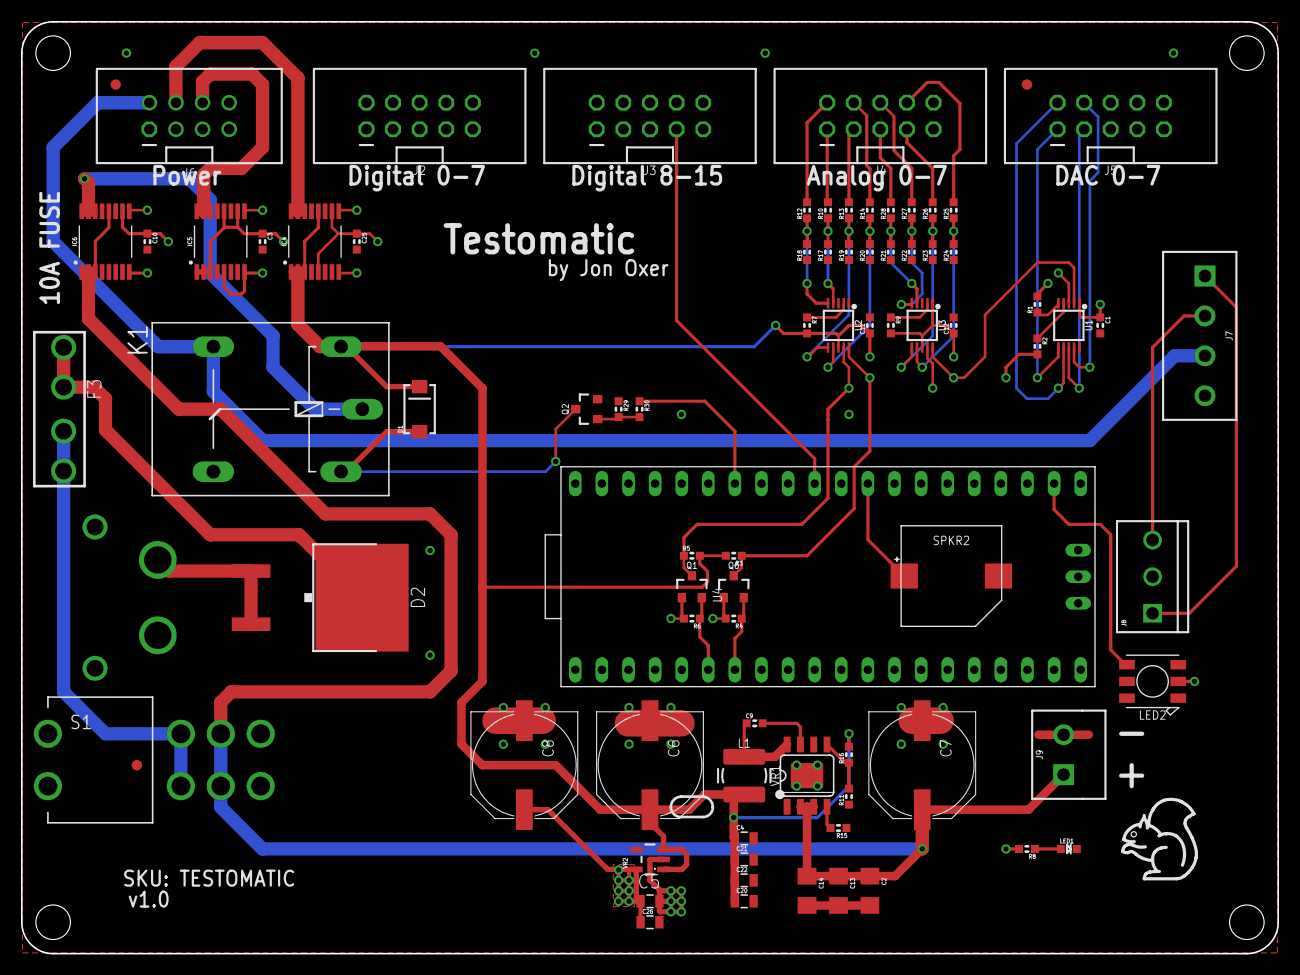
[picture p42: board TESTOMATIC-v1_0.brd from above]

Board: 4 copper layers, 120.0 x 89.0 mm, 82 parts (0 on the bottom side), 67 nets.

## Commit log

2024-06-25 Initial import
    [TESTOMATIC-v1_0.brd, TESTOMATIC-v1_0.sch]
2024-07-28 Added pin allocations document.
2024-07-28 Added notes about CAN bus.
2024-08-22 Added v2.0 hardware files and annotated images.
    [TESTOMATIC-v2_0.brd, TESTOMATIC-v2_0.sch]
2024-08-22 Fixed GPIO voltage in docs.
2024-08-25 Replaced render of v2 with photo of prototype.
2025-02-23 Updates to improve clearance of I/O modules and lower chassis deck.
2025-03-06 Added pic of assembled v2.2 board.
2025-03-06 Added v2.2 design files in Eagle format.
    [TESTOMATIC-v2_2.brd, TESTOMATIC-v2_2.sch]
2025-03-31 Added design files for test module breakout and mechanicals.
    [Module Plate Template.f3d, TMMOD-BREAKOUT-v1_1.3mf, TMMOD-BREAKOUT-v1_1.brd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]
2025-03-31 Added reference material for devices that may interface with Testomatic
2025-04-13 Added chassis design files.
    [Back Plate.dxf, Back Plate.f3d, Base Plate.dxf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]
2025-09-24 Added v2.3 design files and images.
    [TESTOMATIC-v2_3.brd, TESTOMATIC-v2_3.sch]
2025-12-30 Added designs for LED colour sensor shrouds
    [Shroud 0603 lateral.f3d, Shroud 0603 lateral.stl, Shroud 0603 straight.f3d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]
2026-02-02 Replaced image of v1 chassis with v2
2026-08-29 Switch to the Test Suite Package format and rename hard_fail
    Register now delivers a Test Suite Definition inside a Test Suite
    Package. This is a ZIP archive that uses the old JSON file name
    pattern, for example `{sku}-hw{hw_version}-test-suite-v{version}.zip`.
    The archive contains `test-suite-definition.json` at its root, plus
    any files a step needs, such as a firmware binary for an
    UPLOAD_FIRMWARE step.
    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
